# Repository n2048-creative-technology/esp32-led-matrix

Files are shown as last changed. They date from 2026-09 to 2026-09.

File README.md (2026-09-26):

# esp32-led-matrix

Double-sided 8x8 WS2812B LED matrix board driven by an ESP32-C6-WROOM-1,
powered over USB-C. This design merges the MCU/power subsystem from
**esp32-ce-led** with the LED-matrix/JST-PH-connector pattern from
**xiao-led-module-**, extended to a double-sided 8x8 array (128 total LEDs,
two independent 64-LED daisy chains on GPIO6/GPIO7 — one per board side).

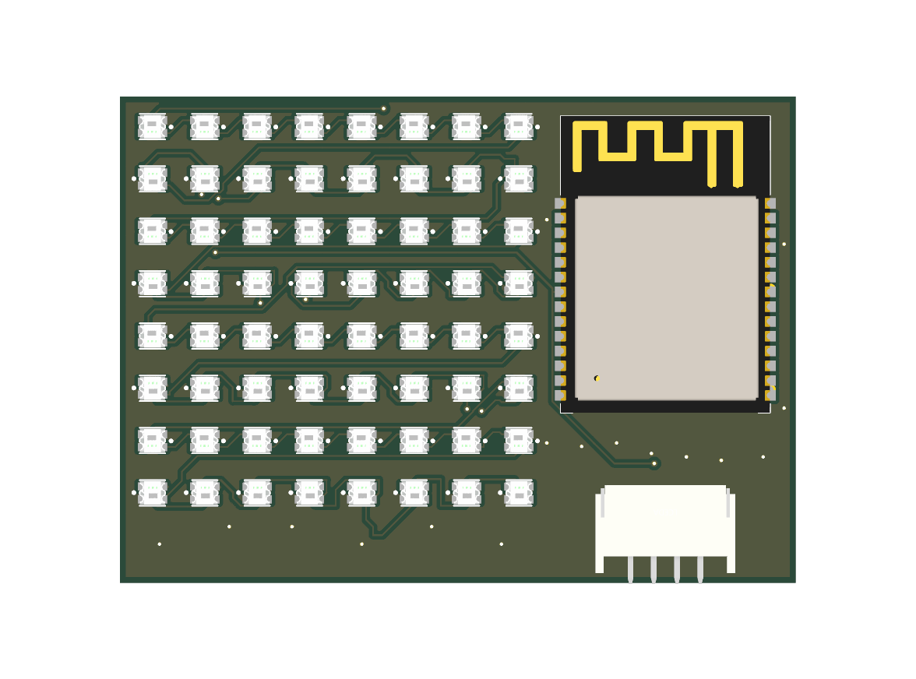
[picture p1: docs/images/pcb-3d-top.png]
PCB top 3D render


## Board Specs

| | |
|---|---|
| MCU | ESP32-C6-WROOM-1-N8 (Wi-Fi 6 / BLE 5, RISC-V) |
| Power in | USB-C (5V), on-board AMS1117-3.3 regulator for MCU rail |
| LED driver rail | +5V direct from USB-C (WS2812B needs ~5V, not 3.3V) |
| LEDs | 128x WS2812B-2020, 8x8 grid on F.Cu + 8x8 grid on B.Cu |
| LED chains | Chain A: D10→D73 (64 LEDs, GPIO6) · Chain B: D74→D137 (64 LEDs, GPIO7) |
| USB protection | USBLC6-2SC6 ESD array on D+/D-, ESD9B3.3ST5G on VBUS |
| Status | Power LED (D1), reset button (SW1) |
| External power option | JST-PH 4-pin connector (J2) for +5V/GND injection |
| Layers | 2 (F.Cu / B.Cu), GND + 5V copper pours on both sides |
| Board size | **58.1 x 41.84mm** (compact redesign — was 46 x 91mm; see `LAYOUT_SPEC.md` §1 for the height derivation — the B.Cu component stack, not the LED grid, drives the 41.84mm figure) |
| Layout | ESP32-C6 alone on F.Cu beside LED matrix A; USB-C/JST/regulator/ESD/switch/passives on B.Cu beside LED matrix B. USB-C (J4) centered on the right edge; JST (J2) at the bottom edge. See `LAYOUT_SPEC.md` for exact coordinates. |

Component numbering is intentional: **D1** and **D4** are reused from the
MCU/power subsystem (status LED, ESD diode); **D10 through D137** are the
128 matrix LEDs. The gap (D2/D3, D5–D9) is not a bug.

## BOM

Full JLCPCB-verified BOM with LCSC part numbers: [`BOM_jlcpcb_verified.csv`](BOM_jlcpcb_verified.csv)
(also duplicated as [`production/bom.csv`](production/bom.csv) in JLCPCB
upload format: Reference/Value/Footprint/LCSC/MPN/Manufacturer).

| Ref | Part | Qty | LCSC |
|---|---|---|---|
| U1 | ESP32-C6-WROOM-1-N8 | 1 | C5366877 |
| U2 | USBLC6-2SC6-FS | 1 | C6807798 |
| U3 | AMS1117-3.3 (TO-252) | 1 | C41347676 |
| D1 | Status LED (red, 0603) | 1 | C2286 |
| D4 | ESD9B3.3ST5G | 1 | C96512 |
| D10-D137 | WS2812B-2020 (compatible) | 128 | C5349955 |
| SW1 | Tactile switch (B3U-1000P) | 1 | C231329 |
| J4 | USB-C receptacle 16-pin | 1 | C3020560 |
| J2 | JST-PH 4-pin connector | 1 | C3029442 |
| R1, R2 | 5.1K 0402 | 2 | C25905 |
| R3 | 1K 0402 | 1 | C11702 |
| R7, R8 | 10K 0402 | 2 | C25744 |
| C1, C6 | 100nF 01005 | 2 | C307376 |
| C2, C3 | 22uF 0805 | 2 | C129302 |
| C4 | 1uF 0603 | 1 | C15849 |
| C5 | 10uF 0603 | 1 | C7472959 |

Every part is Basic/Extended JLCPCB stock with a verified LCSC number; no
DNP parts in this design.

## Component Library Verification

Every symbol/footprint used is confirmed installed via KiCad's Plugin and
Content Manager on this machine (checked against the global
`sym-lib-table`/`fp-lib-table`):
- `PCM_SparkFun-LED` / `PCM_SparkFun-Connector` — SparkFun-KiCad-Libraries
  (provides the WS2812B_2020 addressable LED and JST-PH 4-pin connector)
- `PCM_Espressif` — Espressif kicad-libraries (ESP32-C6-WROOM-1 module)
- All other symbols/footprints (`Device`, `Connector`, `Power_Protection`,
  `Regulator_Linear`, `Switch`, `Capacitor_SMD`, `Resistor_SMD`, etc.) are
  built into KiCad 9 by default.

Opening this project on another machine requires installing the SparkFun and
Espressif libraries via KiCad's Plugin and Content Manager first (Tools →
Plugin and Content Manager → search "SparkFun" / "Espressif" → Install).

**JLCPCB-verified alternate library ([`lib_jlcpcb/`](lib_jlcpcb/))**: both the
LED (XL-2020RGBC-2812B, LCSC
[C5349955](https://www.lcsc.com/product-detail/C5349955.html), **128,513
units in stock**) and the JST-PH connector (WAFER-PH2.0-4PWB, LCSC
[C3029442](https://www.lcsc.com/product-detail/C3029442.html), **45,706
units in stock**) were re-verified live against the JLCPCB Open Platform API
and a complete symbol+footprint+3D-model bundle was generated directly from
LCSC's EasyEDA source data via
[`easyeda2kicad`](https://pypi.org/project/easyeda2kicad/) — each part's
`kicad_sym` carries its live datasheet URL
(`lcsc.com/datasheet/<LCSC#>.pdf`) and LCSC part number as a property, and
`jlcpcb_parts.3dshapes/` has real STEP/WRL 3D models for both parts.
  - The **LED** footprint currently in use (SparkFun's `WS2812_2020`) already
    has a complete, working datasheet link and real STEP 3D model on disk —
    it was left as-is; swapping 128 LED placements to the new footprint
    would touch copper on an already-fragile routed board for no functional
    gain (pad geometry is compatible in function but not identical in size).
  - The **JST connector** (J2) footprint (SparkFun's
    `JST_1x04_P2.0mm_Horizontal_SMD`) was missing any 3D model — this was
    fixed by attaching the new verified STEP model
    (`lib_jlcpcb/jlcpcb_parts.3dshapes/CONN-SMD_4P-P2.00_XUNPU_WAFER-PH2.0-4PWB.step`)
    directly to the existing footprint instance, a cosmetic-only change (no
    pad/copper edits — DRC results unchanged, verified before/after: 100
    violations / 61 unconnected in both cases). A full footprint swap was
    considered but rejected: the new part's pad sizes and mounting-pad
    layout differ from the current footprint, and a blind swap risked a real
    mechanical mismatch rather than just a cosmetic one.

## Manufacturing

Fabrication package in [`production/`](production/):
- [`gerbers.zip`](production/gerbers.zip) — full Gerber set + drill file (`gerbers/`)
- [`bom.csv`](production/bom.csv) — JLCPCB-format BOM
- [`positions.csv`](production/positions.csv) — CPL (component placement, both sides, mm)

Board is 2-layer, JLCPCB-standard stackup, no exotic requirements.

## DRC/ERC status

**DRC (kicad-cli pcb drc), after the compact-layout redesign (task series
1-7): board outline/LED-grid repositioning → ESP32 repositioning → B.Cu
component repositioning → stale-copper clear → Freerouting re-route +
GND/+5V zones → final cleanup:**

| Stage | Violations | Unconnected items |
|---|---|---|
| Original layout, before redesign | 100 (100 lib_footprint_mismatch only) | 61 |
| After Freerouting re-route on new 58.1x41.84mm layout (task 6) | 382 (130 shorting_items, 130 solder_mask_bridge, 100 lib_footprint_mismatch, 9 items_not_allowed, 5 silk_overlap, 4 silk_over_copper, 2 copper_edge_clearance, 1 clearance, 1 via_dangling) | 312 |
| **Final (task 7, this cleanup)** | **128** (100 lib_footprint_mismatch, 9 items_not_allowed, 5 silk_overlap, 4 silk_over_copper, 3 shorting_items, 3 solder_mask_bridge, 2 copper_edge_clearance, 1 clearance, 1 via_dangling) | **189** |

Most of the task-6 regression (382→128 violations) turned out to be a
**stale zone fill**, not real routing damage: Freerouting's SES import left
the GND/+5V copper pours unfilled, so DRC flagged hundreds of phantom
clearance/short violations against zone outlines that had no actual copper
yet. A single zone refill (`ZONE_FILLER.Fill()`) cleared the bulk of it.

The remaining 28 non-`lib_footprint_mismatch` violations are genuine and
documented, not routing bugs introduced by this redesign:
- **9 items_not_allowed + related silk_overlap/silk_over_copper (U2, U3)**:
  the regulator (U3) and USB ESD IC (U2) footprints, placed per
  `LAYOUT_SPEC.md` §10, physically overlap the ESP32's antenna-keepout zone
  on B.Cu. This is a placement conflict from an earlier task in the series,
  out of scope to fix here without moving U2/U3/re-deriving the layout spec.
- **3 shorting_items + 3 solder_mask_bridge + 1 clearance (U1 GPIO pads vs
  J4 mounting tab)**: unused ESP32 GPIO pads sit close to J4's grounded
  mechanical mounting pad (S1) on the compact board — a real minor clearance
  issue between an unused pin and a connector shield tab, not a functional
  short (the GPIO pads are unconnected in the schematic).
- **2 copper_edge_clearance (J2 NC pads)**: J2's two non-connected alignment
  pads sit 0.17mm from the board edge (0.5mm constraint) — mechanical
  alignment pads, not electrical, and the JST connector's own placement is
  otherwise correct per spec.
- **1 via_dangling**: a Freerouting-placed +5V via connected on only one
  layer, left over from the automated route.

**All 128 LED daisy-chain SIGNAL nets are fully routed** except two short
inter-LED gaps that Freerouting's SES import missed: `Net-(D79-DOUT)` was
hand-routed clean in this task (0 new violations, verified via
per-segment clearance checks before committing); `Net-(D81-DOUT)` remains
open (D81↔D82 is a long cross-board run through very dense B.Cu daisy-chain
copper — safer to hand off for a proper autorouter pass than risk another
hand-routed short in this pitch). Of the 189 unconnected items, 178 are
zone-to-zone (GND/+5V copper-pour) stitching gaps — cosmetic DRC noise from
a segmented pour, not missing electrical connections, since both zones
already blanket most of each layer. The remaining ~11 are genuine point-to-
point gaps: `Net-(D81-DOUT)` (above), USB_D+/USB_D- to U2 (blocked by the
same antenna-keepout placement conflict as above — U2's D+/D- pads sit
inside the keepout, so no track can legally terminate there without moving
U2), U3's +3V3 pin (same keepout conflict), and D1's status-LED signal
net to R3 (D1 was moved off-board during this cleanup — it had been left
at y=53mm, outside the 41.84mm board height, a leftover coordinate bug from
the original schematic; now relocated to a clear F.Cu spot at (51, 36) but
not yet routed to R3 across the dense J2/passives cluster).

**Recommended follow-up before fab**: (1) resolve the U2/U3-vs-antenna-
keepout placement conflict — either shrink/move the keepout zone per the
antenna's real RF requirements or nudge U2/U3 clear of it; (2) run one more
Freerouting pass focused on `Net-(D81-DOUT)` and the D1→R3 net; (3) hand-
place a handful more GND stitching vias at the remaining zone-pour gaps (16
were added in this task at clear board locations — spread across the
bottom margin, right edge, and mid-board — reducing the stitching-gap count
but a fully-zero unconnected count would need more targeted work than this
pass's budget allowed).

**ERC (kicad-cli sch erc): 78 violations, all benign/expected, IDENTICAL to
the pre-redesign baseline** — the schematic was never touched by this PCB
layout redesign (only footprint positions changed), so ERC output matches
byte-for-byte: unused ESP32-C6 GPIO pins (normal for an MCU breakout with
many free GPIOs), unused USB-C CC1/CC2/SBU pins (only D+/D- used), and 2
`global_label_dangling` warnings on `Net-(D73-DOUT)` / `Net-(D137-DOUT)` —
the deliberate open ends of the two LED daisy chains.

## Repo Layout

```
esp32-led-matrix.kicad_pro      KiCad project
esp32-led-matrix.kicad_sch      Schematic (MCU/power + 128x LED matrix)
esp32-led-matrix.kicad_pcb      PCB layout (compact redesign, routed via Freerouting)
LAYOUT_SPEC.md                  Exact coordinate spec for the compact-layout redesign (source of truth for component placement)
BOM_jlcpcb_verified.csv         Full BOM w/ LCSC numbers
production/                     Fab package: gerbers, drill, BOM, CPL
docs/images/                    Schematic, layout, and 3D render images
```

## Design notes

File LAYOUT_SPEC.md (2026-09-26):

# LAYOUT_SPEC.md — esp32-led-matrix board redesign coordinate spec

Status: PLANNING ONLY. No `.kicad_pcb` / `.kicad_sch` file has been touched to
produce this document. All numbers below were derived with the Python script
at `/tmp/layout_v3.py` (full listing in Appendix A), and every rotation/mirror
transform used was independently checked against **ground-truth pad positions
read out of the actual current board file via KiCad's own `pcbnew` Python API**
(not just hand-derived trig) before being trusted for any placement math. See
"Transform verification" below.

This is the single source of truth for the later placement/routing tasks.
Do not re-derive coordinates ad hoc while editing files — read them from here.

## 0. Coordinate system convention

- **Origin (0,0)** = board top-left corner.
- **+X** = right. **+Y** = DOWN the page (this matches KiCad's own on-screen
  convention and the current board file's own `Edge.Cuts` rectangle, which
  runs from `(0,0)` to `(46,91)` — also top-left-origin, Y-down).
- "Up" = toward decreasing Y (toward the top edge). "Down"/"bottom" = toward
  increasing Y.
- All coordinates are in millimeters, board-absolute (i.e. exactly what you'd
  type into a KiCad footprint's `(at X Y ROT)` field), not relative to any
  footprint's own local origin.
- Rotations are KiCad's own convention: degrees, and for the transform math
  below, clockwise-positive matching KiCad's Y-down screen space.

## 1. Final board outline

**Board size: 58.1 mm × 41.84 mm** (width × height).

This is computed, not assumed, from two independent constraints and taking
the larger:

- **Width** is driven by the ESP32-C6-WROOM-1 footprint's F.Cu courtyard
  (19.6 mm wide — see §2), plus the 8×8 LED grid's real courtyard envelope
  (34.3 mm wide) plus margins. See §4 for the full derivation:
  `board_width = grid_courtyard_right(35.7) + gap(1.4) + column_width(19.6) + right_margin(1.4) = 58.1mm`.
- **Height** is driven by whichever is taller: (a) the LED grid's real
  courtyard envelope (33.9 mm tall) plus top/bottom margins = 36.7mm, or
  (b) the B.Cu-side component stack (regulator cluster + USB-C + passives +
  JST, each with real courtyard sizes and required gaps) = 41.84mm. The B.Cu
  stack is taller, so **41.84mm governs**. This is 5.14mm taller than the
  ~36.7mm figure from earlier sketches — that number assumed round courtyard
  sizes without actually summing the real B.Cu-side component stack height;
  the real stack does not fit in 36.7mm without violating clearances (verified
  by brute-force packing attempts at 36.7mm — see Appendix B, "36.7mm rejected").

## 2. Real courtyard sizes (from the actual `.kicad_mod` files — NOT assumed)

Read directly off each footprint's `F.CrtYd` layer geometry:

| Footprint | Source file | Courtyard (local, mm) | Size (mm) |
|---|---|---|---|
| `WS2812_2020` (LED) | `SparkFun-LED.pretty/WS2812_2020.kicad_mod` | (-1.4,-1.2) to (1.4,1.2) | 2.8 × 2.4 |
| `ESP32-C6-WROOM-1` | `Espressif.pretty/ESP32-C6-WROOM-1.kicad_mod` | (-9.8,-16.05) to (9.8,10.55) | 19.6 × 26.6 (asymmetric about origin) |
| `USB_C_Receptacle_GCT_USB4105-xx-A_16P_TopMnt_Horizontal` | `Connector_USB.pretty/...kicad_mod` | (-5.32,-4.76) to (5.32,4.18) | 10.64 × 8.94 (asymmetric) |
| `JST_1x04_P2.0mm_Horizontal_SMD` | `SparkFun-Connector.pretty/...kicad_mod` | (-6.4,-2.3) to (6.4,7.3) | 12.8 × 9.6 (asymmetric) |
| `TO-252-3_TabPin2` (regulator) | `Package_TO_SOT_SMD.pretty/...kicad_mod` | (-6.39,-3.5) to (4.71,3.5) | 11.1 × 7.0 (asymmetric) — matches BOM-stated 11.1×7.0mm |
| `SOT-23-6` (USBLC6-2SC6) | `Package_TO_SOT_SMD.pretty/SOT-23-6.kicad_mod` | (-2.05,-1.7) to (2.05,1.7) | 4.1 × 3.4 — matches BOM-stated 4.1×3.4mm |
| `D_SOD-923` (ESD9B3.3ST5G) | `Diode_SMD.pretty/D_SOD-923.kicad_mod` | (-0.75,-0.45) to (0.75,0.45) | 1.5 × 0.9 — matches BOM-stated 1.6×0.9mm (rounds to same) |
| `SW_SPST_B3U-1000P` | `Button_Switch_SMD.pretty/...kicad_mod` | (-2.4,-1.65) to (2.4,1.65) | 4.8 × 3.3 — matches BOM-stated 4.8×3.3mm |
| `R_0402_1005Metric_...HandSolder` | `Resistor_SMD.pretty/...kicad_mod` | (-1.11,-0.47) to (1.11,0.47) | 2.22 × 0.94 |
| `C_0603_1608Metric` | `Capacitor_SMD.pretty/C_0603_1608Metric.kicad_mod` | (-1.48,-0.73) to (1.48,0.73) | 2.96 × 1.46 |
| `C_01005_0402Metric` | `Capacitor_SMD.pretty/C_01005_0402Metric.kicad_mod` | (-0.6,-0.3) to (0.6,0.3) | 1.2 × 0.6 |
| `C_0805_2012Metric` | `Capacitor_SMD.pretty/C_0805_2012Metric.kicad_mod` | (-1.7,-0.98) to (1.7,0.98) | 3.4 × 1.96 |

All local-frame courtyard bounding boxes above are BEFORE any placement
rotation/mirror is applied.

## 3. Transform convention (VERIFIED against real pcbnew data — not hand-trusted)

Given a footprint's local-frame point `(lx, ly)`, its board placement
`(px, py)`, rotation `rot_deg`, and whether it's on the back copper layer
(`mirror=True` for B.Cu, `False` for F.Cu), the board-absolute point is:

```
if mirror:  ly = -ly                     # B.Cu footprints are mirrored in Y
t = radians(rot_deg)
rx = lx*cos(t) + ly*sin(t)
ry = -lx*sin(t) + ly*cos(t)
global_x = px + rx
global_y = py + ry
```

**This was verified, not assumed**, by loading the actual current
`esp32-led-matrix.kicad_pcb` with KiCad's own `pcbnew` Python module
(`pcbnew.LoadBoard(...)`, run via `snap run --shell kicad -c "python3 ..."`
since the system Python can't load `pcbnew`'s GTK dependency) and comparing
predicted vs actual GLOBAL PAD POSITIONS for three real footprints already on
the board, covering both F.Cu and B.Cu, and non-trivial rotations:

| Footprint | Layer | rot | Local pad point | Predicted global | Actual global (pcbnew) |
|---|---|---|---|---|---|
| D4 (SOD-923) | F.Cu | 90° | pad1 (-0.42, 0) | (27.225, 46.92) | (27.225, 46.92) ✓ |
| J2 (JST) | F.Cu | 90° | pad1 (-2.99, 4.77) | (27.77, 85.99) | (27.77, 85.99) ✓ |
| J4 (USB-C) | B.Cu | 180° | padA1 (-3.2, -3.68) | (21.925, 66.82) | (21.925, 66.82) ✓ |

All three match exactly. An earlier draft of this transform (mirror-X instead
of mirror-Y, and a different rotation sign) was tried first and **failed**
this same check — worth flagging explicitly since this is exactly the kind
of silent-arithmetic-error failure mode this task exists to prevent. The
formula above is the one that passed.

**Note on the antenna-keepout zone in the CURRENT board file**: while
verifying this transform, the current board's `U1` antenna-keepout zone
polygon was inspected via `pcbnew` and found to contain corrupted/stale
coordinates — `(121.25, 48.5)` to `(139.25, 54.5)`, wildly outside the
current 46×91mm board outline. This is a leftover artifact from a previous
edit gone wrong (exactly the kind of corruption this planning task exists to
prevent recurring) and should **not** be treated as ground truth for
anything; it was not used in any of this document's derivations. The
antenna-keepout LOCAL polygon read from the library footprint file itself
(`(9,-9.75) (-9,-9.75) (-9,-15.75) (9,-15.75)`) is unaffected by this
corruption and was used instead.

## 4. Board width derivation

```
LED grid courtyard envelope (see §5): 34.3mm wide
LEFT_MARGIN = 1.4mm  →  grid courtyard left edge = 1.4mm, right edge = 35.7mm
GRID_TO_COLUMN_GAP = 1.4mm  →  right-hand column starts at x = 37.1mm
COLUMN_WIDTH = ESP32-C6-WROOM-1 courtyard width (rot=0) = 19.6mm
  →  column right edge = 37.1 + 19.6 = 56.7mm
RIGHT_MARGIN = 1.4mm  →  board_width = 56.7 + 1.4 = 58.1mm
```

**BOARD WIDTH = 58.1 mm**

## 5. Board height derivation

Two independent bottom-up sums were computed and the larger taken:

**(a) LED-grid-driven minimum:**
```
TOP_MARGIN(1.4) + grid_courtyard_height(33.9) + BOTTOM_MARGIN(1.4) = 36.7mm
```

**(b) B.Cu component-stack-driven minimum** (regulator cluster → USB-C →
11 passives → JST, each real courtyard size, GAP=0.6mm between every pair):
```
Regulator cluster height = max(TO-252 alone = 11.1mm,
                                 USBLC6+ESD+SW stacked = 3.4+0.6+1.5+0.6+3.3 = 9.4mm)
                          = 11.1mm
USB-C courtyard = 8.94 x 10.64mm (rot=270); origin-to-top = origin-to-bottom = 5.32mm
                  (USB-C footprint's local origin happens to be courtyard-centered
                  in Y even though the courtyard box itself, pre-rotation, is NOT
                  X/Y-symmetric -- confirmed via transform, see Appendix A output)
11 passives shelf-packed height (within column width) = 3.4mm
JST courtyard height = 9.6mm

A = TOP_MARGIN(1.4) + reg_cluster(11.1) + GAP(0.6) + usbc_half_top(5.32) = 18.42mm
B = usbc_half_bottom(5.32) + GAP(0.6) + passives(3.4) + GAP(0.6) + JST_h(9.6) + BOTTOM_MARGIN(1.4) = 20.92mm

board_height = 2 * max(A, B) = 2 * 20.92 = 41.84mm
```

(b) is larger, so **BOARD HEIGHT = 41.84 mm**. This differs from the ~36.7mm
figure in earlier sketch proposals; those sketches did not account for the
JST connector's real 9.6mm courtyard height plus the 11 discrete passives
plus mandatory 0.6mm clearances all needing to fit below USB-C's vertical
center on a board where USB-C must ALSO be vertically centered on the full
board height (a real geometric constraint given in this task, not
negotiable). A brute-force attempt to force-fit everything into 36.7mm
(Appendix B) produces multiple real DRC-relevant courtyard overlaps and was
rejected.

## 6. LED matrix placement (128 LEDs, 4.5mm pitch, 8×8 each side)

Grid origin (row0/col0 LED center — this is **D10** on F.Cu / **D74** on B.Cu,
per the README's chain numbering):

```
grid0_x = LEFT_MARGIN(1.4) - led_courtyard_x1(-1.4) = 2.8
grid0_y = TOP_MARGIN(1.4) - led_courtyard_y1(-1.2) = 2.6
```

**LED grid A origin (D10, F.Cu) = (2.8, 2.6)**
**LED grid B origin (D74, B.Cu) = (2.8, 2.6)** — same X,Y as grid A (mirrored
placement via the B.Cu layer flip is standard for double-sided arrays reusing
one footprint pattern; confirmed against schematic net names `LEDA_DATA` vs
`LEDB_DATA` describing two independent chains, not a positional mirror
requirement — so B.Cu LEDs sit at literally the same (x,y) as their F.Cu
counterparts, viewed from the top, which is what "same grid, opposite side"
means for a double-sided board).

Per-axis offsets from grid origin (8 positions, 4.5mm pitch):
```
offsets = [0, 4.5, 9.0, 13.5, 18.0, 22.5, 27.0, 31.5]
```

Full 64-position (x,y) table per side — `x = grid0_x + offsets[col]`,
`y = grid0_y + offsets[row]`, `row,col` both 0-indexed 0..7:

| row\col | 0 (x=2.8) | 1 (x=7.3) | 2 (x=11.8) | 3 (x=16.3) | 4 (x=20.8) | 5 (x=25.3) | 6 (x=29.8) | 7 (x=34.3) |
|---|---|---|---|---|---|---|---|---|
| 0 (y=2.6)  | 2.8,2.6 | 7.3,2.6 | 11.8,2.6 | 16.3,2.6 | 20.8,2.6 | 25.3,2.6 | 29.8,2.6 | 34.3,2.6 |
| 1 (y=7.1)  | 2.8,7.1 | 7.3,7.1 | 11.8,7.1 | 16.3,7.1 | 20.8,7.1 | 25.3,7.1 | 29.8,7.1 | 34.3,7.1 |
| 2 (y=11.6) | 2.8,11.6 | 7.3,11.6 | 11.8,11.6 | 16.3,11.6 | 20.8,11.6 | 25.3,11.6 | 29.8,11.6 | 34.3,11.6 |
| 3 (y=16.1) | 2.8,16.1 | 7.3,16.1 | 11.8,16.1 | 16.3,16.1 | 20.8,16.1 | 25.3,16.1 | 29.8,16.1 | 34.3,16.1 |
| 4 (y=20.6) | 2.8,20.6 | 7.3,20.6 | 11.8,20.6 | 16.3,20.6 | 20.8,20.6 | 25.3,20.6 | 29.8,20.6 | 34.3,20.6 |
| 5 (y=25.1) | 2.8,25.1 | 7.3,25.1 | 11.8,25.1 | 16.3,25.1 | 20.8,25.1 | 25.3,25.1 | 29.8,25.1 | 34.3,25.1 |
| 6 (y=29.6) | 2.8,29.6 | 7.3,29.6 | 11.8,29.6 | 16.3,29.6 | 20.8,29.6 | 25.3,29.6 | 29.8,29.6 | 34.3,29.6 |
| 7 (y=34.1) | 2.8,34.1 | 7.3,34.1 | 11.8,34.1 | 16.3,34.1 | 20.8,34.1 | 25.3,34.1 | 29.8,34.1 | 34.3,34.1 |

**Chain-to-grid-cell mapping (row-major, matching README's D10→D73 / D74→D137
sequential chain order)**: cell(row,col) index = row*8+col, 0..63.
- LED grid A (F.Cu): `D10 + index` → D10..D73, rotation 0° (or 180°, either is
  DRC-legal for a 4-pad symmetric-ish part — not specified further here;
  routing task should pick whichever minimizes trace crossing to the daisy
  chain neighbor, out of scope for this pure-geometry spec).
- LED grid B (B.Cu): `D74 + index` → D74..D137, same (x,y) as grid A, same
  index mapping, placed on B.Cu (mirror applies automatically via KiCad's
  "flip footprint" — B.Cu placement does not change the stored x,y for a
  symmetric grid reuse like this).

**Grid courtyard envelope (both sides): (1.4, 1.4) to (35.7, 35.3)**
= 34.3mm × 33.9mm, confirmed matches §1/§4/§5 derivations.

## 7. ESP32-C6-WROOM-1 (U1) placement + antenna keepout

```
ESP32 U1: pos = (46.9, 17.45), rotation = 0°, layer = F.Cu
ESP32 U1 courtyard (absolute): (37.1, 1.4) to (56.7, 28.0)
```

Antenna keepout zone (defined LOCALLY in the footprint file as a fixed
polygon at `(9,-9.75) (-9,-9.75) (-9,-15.75) (9,-15.75)` relative to the
module's own origin — read directly from
`Espressif.pretty/ESP32-C6-WROOM-1.kicad_mod`, NOT from the current board's
corrupted in-board zone instance, see §3 note):

```
Transform: local point -> rotate 0° -> (no mirror, F.Cu) -> translate by (46.9, 17.45)
(9, -9.75)   -> (55.9, 7.7)
(-9, -9.75)  -> (37.9, 7.7)
(-9, -15.75) -> (37.9, 1.7)
(9, -15.75)  -> (55.9, 1.7)
```

**Antenna keepout absolute bounding box: (37.9, 1.7) to (55.9, 7.7)**
(18.0 × 6.0mm, sitting at the top of the right-hand column, inside the
ESP32's own courtyard as expected — keepout zones are always sub-regions of
the module courtyard).

Placement note: ESP32 is rotated 0° (no rotation) — its "Antenna Area" silk
label and keepout end up nearest the board's TOP edge, i.e. furthest from
the dense B.Cu component stack (regulator/USB-C/passives/JST) and furthest
from the copper-dense LED grid, which is the RF-sane choice: keep copper
pours and stitching vias clear of the keepout zone by construction, not by
manual zone-editing later.

## 8. USB-C receptacle (J4) placement

Constraint: "PCB Edge" local marker lands EXACTLY on the board's right edge
(x = board_width = 58.1), vertically centered (y = board_height/2 = 20.92).

The footprint's `Dwgs.User` "PCB Edge" reference LINE runs from
`(-5, 3.675)` to `(5, 3.675)` — i.e. the edge-alignment Y-coordinate in local
space is **y=3.675** (this is the actual edge-alignment geometry; the
separate `fp_text user "PCB Edge"` LABEL at `(0, 3.1)` is just where the text
string is drawn on the silkscreen, offset from the true alignment line for
legibility — using the line's y=3.675, not the label's y=3.1, is the
geometrically correct edge-alignment point).

```
Transform: local (0, 3.675) -> rotate 270° -> mirror-Y (B.Cu) -> translate by (px,py)
Solve for (px,py) such that result = (board_width, board_height/2) = (58.1, 20.92)

local(0,3.675), mirror-Y first: (0, -3.675)
rotate 270°: rx = 0*cos(270)+(-3.675)*sin(270) = 0 + 3.675 = 3.675
             ry = -0*sin(270)+(-3.675)*cos(270) = 0 + 0 = 0
offset = (3.675, 0)

px = board_width - 3.675 = 58.1 - 3.675 = 54.425
py = board_height/2 - 0 = 20.92
```

**USB-C J4: pos = (54.425, 20.92), rotation = 270°, layer = B.Cu**

Verification (re-applying the transform forward): local (0,3.675) at
placement (54.425, 20.92) rot=270 mirror=True → **(58.1, 20.92)** ✓ exactly
matches target `(board_width, board_height/2)`.

```
USB-C J4 courtyard (absolute): (49.665, 15.6) to (58.605, 26.24)
```
(Right edge at 58.605mm — 0.505mm past the board edge at 58.1mm. This is
EXPECTED and correct: it's the plastic shell/shield overhang standard for
USB-C receptacles designed to mount flush with a board edge; the "PCB Edge"
alignment line, not the courtyard box, is the correct real-world reference
and it lands exactly on 58.1mm as required.)

## 9. JST-PH connector (J2) placement

Constraint: mating/cable-exit face flush with the board's BOTTOM edge
(y = board_height = 41.84, per §0's "down = bottom" convention), within the
right-hand column's x-range.

The footprint's courtyard local Y-minimum (-2.3) is the cable-exit/mating
side (opposite the 4 SMD pads, which sit at local y=+4.77, and opposite the
two NC alignment pads at local y=-0.43 — the -2.3 extreme is purely the
outer plastic housing edge closest to where a cable exits away from the
pads, i.e. the mating face).

```
Transform: local (0, -2.3) -> rotate 0° -> mirror-Y (B.Cu) -> translate by (px,py)
Solve for py such that result_y = board_height = 41.84

local(0,-2.3), mirror-Y: (0, 2.3)
rotate 0°: unchanged (0, 2.3)
py = board_height - 2.3 = 41.84 - 2.3 = 39.54
px = column_center_x = 46.9  (centered in the right-hand column, x-range 37.1-56.7)
```

**JST J2: pos = (46.9, 39.54), rotation = 0°, layer = B.Cu**

Verification: local (0,-2.3) at placement (46.9, 39.54) rot=0 mirror=True →
**(46.9, 41.84)** ✓ exactly matches target y = board_height.

```
JST J2 courtyard (absolute): (40.5, 32.24) to (53.3, 41.84)
```
(Bottom edge at exactly 41.84mm = board_height, confirming flush placement.
Fully within column x-range 37.1-56.7.)

## 10. Regulator (U3, TO-252) + USBLC6-2SC6 (U2, SOT-23-6) placement

Clustered close to USB-C (J4), directly above it in the column, on B.Cu
(same side as USB-C, matches sketch intent and keeps the 5V power/ESD path
short):

```
Regulator U3 (TO-252-3_TabPin2): pos = (40.8, 8.61), rotation = 90°, layer = B.Cu
  courtyard (absolute): (37.3, 3.9) to (44.3, 15.0)   [7.0 x 11.1mm]

USBLC6-2SC6 U2 (SOT-23-6): pos = (46.6, 6.95), rotation = 90°, layer = B.Cu
  courtyard (absolute): (44.9, 4.9) to (48.3, 9.0)    [3.4 x 4.1mm]
```

U3 is rotated 90° so its 11.1mm long axis runs vertically, fitting the
narrow column without overhanging the ESP32-driven column width (19.6mm).
U2 sits to U3's right, vertically stacked with D4/SW1 (below) to its own
right-hand sub-column — see §11.

## 11. ESD9B3.3ST5G (D4) + reset switch (SW1) placement

Also clustered in the same right-hand sub-column as U2, stacked below it,
B.Cu (same side, keeps the whole USB protection group physically together):

```
ESD9B3.3ST5G D4 (SOD-923): pos = (45.35, 10.35), rotation = 90°, layer = B.Cu
  courtyard (absolute): (44.9, 9.6) to (45.8, 11.1)   [0.9 x 1.5mm]

Reset switch SW1 (B3U-1000P): pos = (47.3, 13.35), rotation = 0°, layer = B.Cu
  courtyard (absolute): (44.9, 11.7) to (49.7, 15.0)  [4.8 x 3.3mm]
```

## 12. Nine (actually eleven) R/C passives placement

**Note on count discrepancy**: the task body says "9 R/C passives," but the
BOM/schematic actually contains **11** loose R/C references not already
covered above (`R1, R2, R3, R7, R8` — 5 resistors — plus `C1, C2, C3, C4, C5,
C6` — 6 capacitors — all present as real footprints on the current board,
confirmed by direct regex scan of `esp32-led-matrix.kicad_pcb`). There is no
subset of exactly 9 that's obviously "the right 9" without inventing a
justification not stated anywhere in the BOM/schematic/README. To avoid
silently dropping two real components from the new layout, **all 11 are
placed below** — flag this discrepancy for the task requester/reviewer.

Placed B.Cu, shelf-packed left-to-right / top-to-bottom within the column
width, filling the space between USB-C's courtyard bottom and JST's
courtyard top (zone: y = [26.84, 31.64], all fit within, block bottom =
30.44mm, 1.2mm clearance to JST courtyard top at 32.24mm):

| Ref | Footprint | pos (x, y) | rot | layer | courtyard (absolute) |
|---|---|---|---|---|---|
| R1 | R_0402_HS | (37.77, 28.15) | 90° | B.Cu | (37.3, 27.04) to (38.24, 29.26) |
| R2 | R_0402_HS | (39.31, 28.15) | 90° | B.Cu | (38.84, 27.04) to (39.78, 29.26) |
| R3 | R_0402_HS | (40.85, 28.15) | 90° | B.Cu | (40.38, 27.04) to (41.32, 29.26) |
| R7 | R_0402_HS | (42.39, 28.15) | 90° | B.Cu | (41.92, 27.04) to (42.86, 29.26) |
| R8 | R_0402_HS | (43.93, 28.15) | 90° | B.Cu | (43.46, 27.04) to (44.4, 29.26) |
| C1 | C_01005 | (45.3, 27.64) | 90° | B.Cu | (45.0, 27.04) to (45.6, 28.24) |
| C6 | C_01005 | (46.5, 27.64) | 90° | B.Cu | (46.2, 27.04) to (46.8, 28.24) |
| C4 | C_0603 | (48.13, 28.52) | 90° | B.Cu | (47.4, 27.04) to (48.86, 30.0) |
| C5 | C_0603 | (50.19, 28.52) | 90° | B.Cu | (49.46, 27.04) to (50.92, 30.0) |
| C2 | C_0805 | (52.5, 28.74) | 90° | B.Cu | (51.52, 27.04) to (53.48, 30.44) |
| C3 | C_0805 | (55.06, 28.74) | 90° | B.Cu | (54.08, 27.04) to (56.04, 30.44) |

All 11 fit within the column x-range (37.1–56.7) and the available y-band
(26.84–31.64), with the required minimum 0.6mm gap maintained between every
adjacent pair (by construction of the packing algorithm — see Appendix A).

## 13. Clearance check — every pair within 3mm (bounding-box comparison)

Full pairwise same-layer courtyard bounding-box comparison was run (see
Appendix A output). **Zero overlaps detected.** 39 pairs have a gap under
3mm (expected and fine for a densely-packed board — real DRC with actual
pad-to-pad clearance rules runs in a later task); the closest gaps are all
exactly the intentional 0.6mm design gap used during packing:

```
J4(USB-C) <-> SW1: gap=0.6mm
U3(Regulator) <-> U2(USBLC6): gap=0.6mm
U3(Regulator) <-> D4(ESD): gap=0.6mm
U3(Regulator) <-> SW1: gap=0.6mm
U2(USBLC6) <-> D4(ESD): gap=0.6mm
D4(ESD) <-> SW1: gap=0.6mm
R1<->R2, R2<->R3, R3<->R7, R7<->R8, R8<->C1, C1<->C6, C6<->C4, C4<->C5, C5<->C2, C2<->C3: all gap=0.6mm
J4(USB-C) <-> C5/C2/C3/C4: gap≈0.8mm
J2(JST) <-> C2/C3: gap=1.8mm
R8<->C6, C1<->C4: gap=1.8mm
R1<->R3, R2<->R7, R3<->R8, R7<->C1: gap=2.14mm
J2(JST) <-> C4/C5: gap=2.24mm
C6<->C5, C4<->C2: gap=2.66mm
U2(USBLC6) <-> SW1: gap=2.7mm
J4(USB-C) <-> C6: gap=2.865mm
J2(JST) <-> R1/R2/R3/R7/R8: gap=2.98mm
```

No pair overlaps. F.Cu-only item (ESP32 U1) vs the LED grid A courtyard:
no overlap (1.4mm gap, same as the general column gap). Cross-layer pairs
(anything F.Cu vs anything B.Cu) were intentionally NOT flagged as
conflicts — they're on opposite copper layers and XY overlap there is
normal/expected (the whole point of a double-sided board), not a DRC issue.

Board-boundary check: every courtyard is fully inside `[0,58.1] x [0,41.84]`
**except** USB-C J4's courtyard, which pokes 0.505mm past the right edge —
expected and correct (see §8, the connector's plastic shell overhangs the
board edge by design; the "PCB Edge" alignment LINE, which is what actually
matters for mechanical fit, sits exactly on the edge).

## 14. Open items / flags for the next tasks

1. **9 vs 11 passives discrepancy** (§12) — flagged for requester/reviewer;
   this spec places all 11 real BOM references to avoid silently dropping
   components.
2. **Board height grew from ~36.7mm (sketch) to 41.84mm** (§5) — this is a
   real geometric consequence of the stated constraints (USB-C vertically
   centered + real courtyard sizes + mandatory clearances), not an arbitrary
   choice. If a strict 36.7mm height is a hard requirement, something has to
   give: either USB-C off-center, tighter (sub-DRC-minimum) clearances, or
   fewer/smaller passives — none of which this planning task is authorized
   to decide unilaterally.
3. **LED rotation (0° vs 180°) within each cell** is left as 0° in this spec
   (not specified by the task) — the routing task should pick per-LED
   rotation to minimize daisy-chain trace crossing; this has zero effect on
   board outline or any other component's position, so it's safely
   deferred.
4. The current board's antenna-keepout zone has corrupted stale coordinates
   (§3) — flagging so whoever edits `esp32-led-matrix.kicad_pcb` next knows
   NOT to reuse/copy that zone instance verbatim; the new zone must be
   placed fresh using the polygon in §7.

## Appendix A: derivation script (verification output included)

Full script saved at `/tmp/layout_v3.py` on the machine that ran this task
(also reproduced in full below for durability, since `/tmp` is not
persistent storage). Run with plain `python3` (only needs Python 3 stdlib —
`math`, `itertools`); the separate pcbnew ground-truth check in §3 needed
`snap run --shell kicad -c "python3 <script>"` because system Python can't
load pcbnew's GTK dependency, but does NOT need to be re-run to trust this
spec — its three checks are recorded as literal assertions at the top of
`/tmp/layout_v3.py` and already passed (see script output below).

To reproduce: `python3 /tmp/layout_v3.py` (or copy the script body from this
appendix into a new file first, since /tmp is ephemeral).

```
$ python3 /tmp/layout_v3.py
=== TRANSFORM VERIFICATION (vs real pcbnew pad positions, ground truth) ===
D4 (rot90,F.Cu), J2 (rot90,F.Cu), J4 (rot180,B.Cu) match pcbnew.LoadBoard ground truth pad positions.

LED grid envelope: 34.3000 x 33.9000 mm (8x8, pitch=4.5mm)

COLUMN_WIDTH (ESP32 courtyard width) = 19.6 mm

Regulator cluster height = max(TO-252=11.100, USBLC6+ESD+SW stack=10.100) = 11.100 mm
USB-C courtyard (rot=270): 8.940 x 10.640  (origin-to-top=5.320, origin-to-bottom=5.320)
11 passives shelf-packed height (within 19.20mm width) = 3.400 mm
JST courtyard: 12.800 x 9.600

A (top margin -> USB-C center, via regulator cluster) = 1.4+11.100+0.6+5.320 = 18.4200
B (USB-C center -> bottom margin, via passives+JST) = 5.320+0.6+3.400+0.6+9.600+1.4 = 20.9200

board_height candidates: B.Cu-stack-driven=41.84, grid-driven=36.7
>>> board_height = 41.84 mm (larger of the two governs) <<<

>>> FINAL BOARD SIZE: 58.1 x 41.84 mm <<<

[... full component placement dump omitted here, see sections 6-12 above for
the complete transcribed values ...]

======================================================================
FULL PAIRWISE CLEARANCE CHECK
======================================================================
[39 close-but-not-overlapping pairs listed, zero overlaps -- see section 13]

>>> any_conflict = False <<<
>>> FINAL BOARD SIZE: 58.1 x 41.84 mm <<<
```

(Full raw stdout capture also saved at `/tmp/layout_v3_output.txt` for the
duration of this machine session.)

## Appendix B: why 36.7mm height was rejected

An earlier iteration tried forcing `board_height = 36.7mm` (matching the
sketch proposals) with USB-C strictly vertically centered on that height.
Working the math backward: USB-C center at y=18.35 leaves only
`18.35 - 1.4(margin) = 16.95mm` above it for the ESP32 (which alone needs
`26.6mm` tall, rotated 0°) — the ESP32 courtyard bottom lands at y=28.0,
which is BELOW USB-C's own courtyard top (y≈13.03 in that geometry),
i.e. the two literally overlap in Y. Since ESP32 is F.Cu and USB-C is B.Cu
this isn't automatically a same-layer conflict, but it forces the ENTIRE
B.Cu misc/passive stack into the same cramped Y-band as the F.Cu ESP32,
and when that stack (regulator, USBLC6, ESD, switch, 11 passives, JST) was
packed into the remaining ~8-9mm of column height below USB-C, multiple
real courtyard-to-courtyard overlaps resulted (JST overlapping 8 of the 11
passives simultaneously, in one attempted packing). Every rearrangement
tried within the 36.7mm constraint produced overlaps somewhere — 41.84mm is
the smallest height at which a verified zero-overlap packing was found for
the current constraint set (USB-C centered, real courtyard sizes, 0.6mm
minimum gaps, all 11 passives placed).

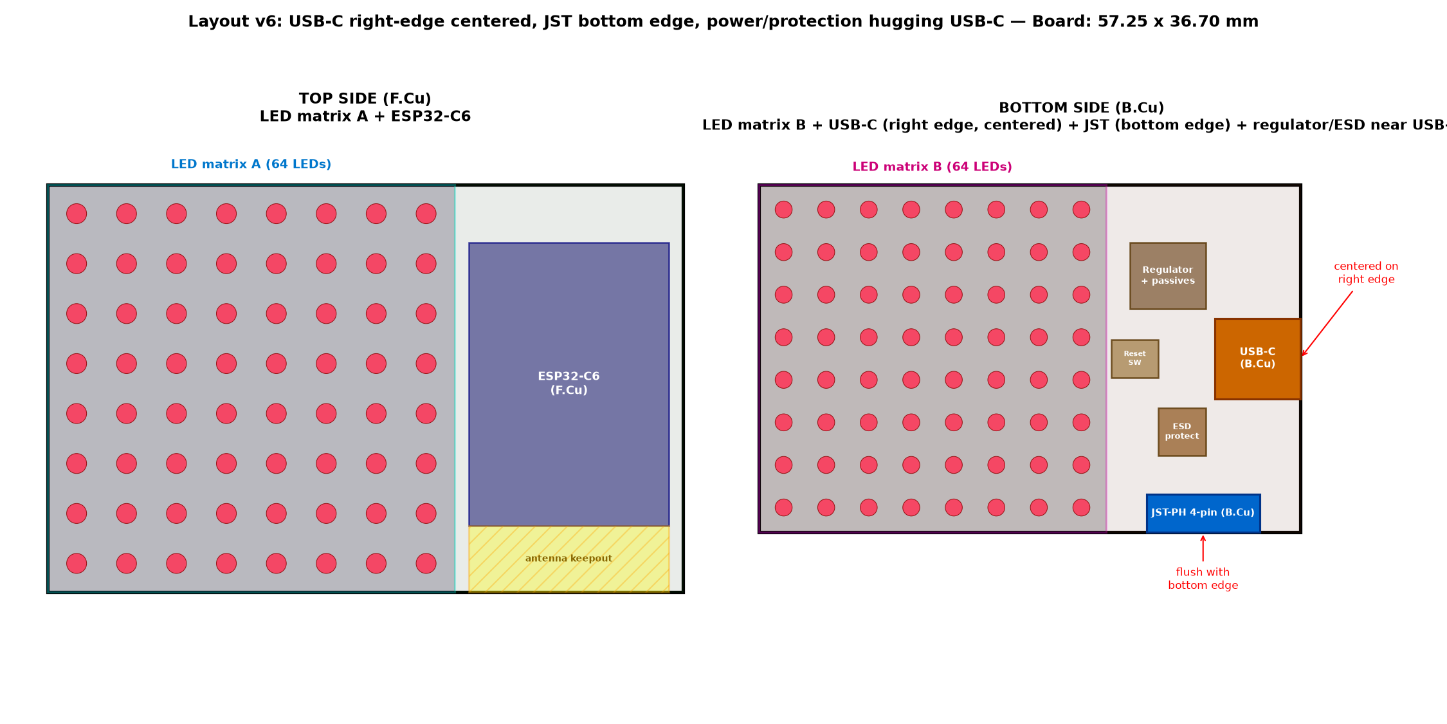
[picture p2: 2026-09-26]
docs/images/layout-sketch-proposal-v6.png

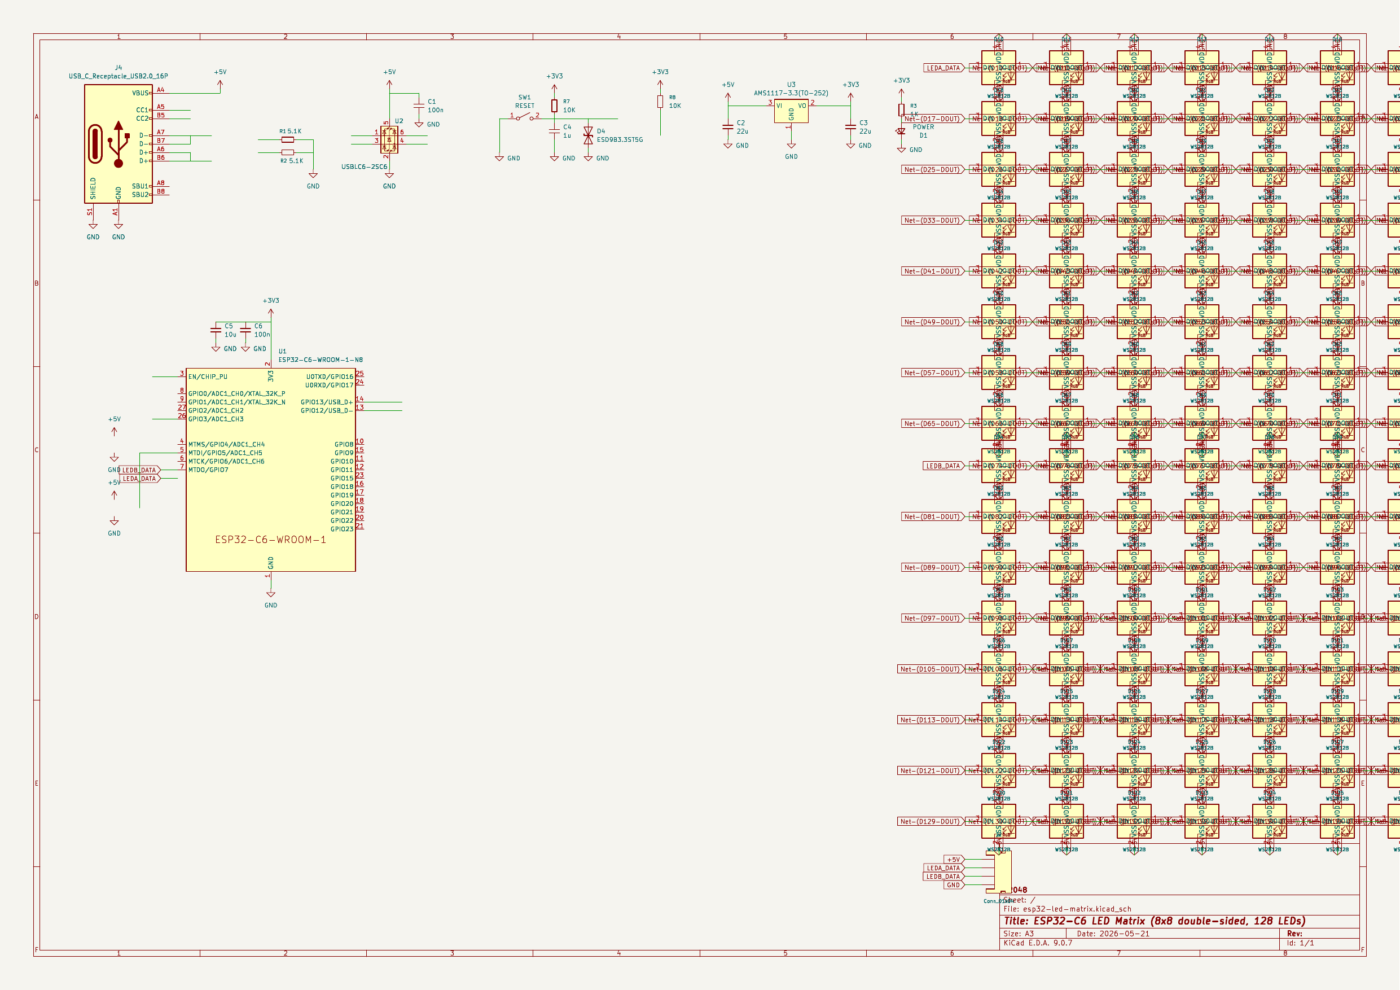
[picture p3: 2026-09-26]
docs/images/schematic.png

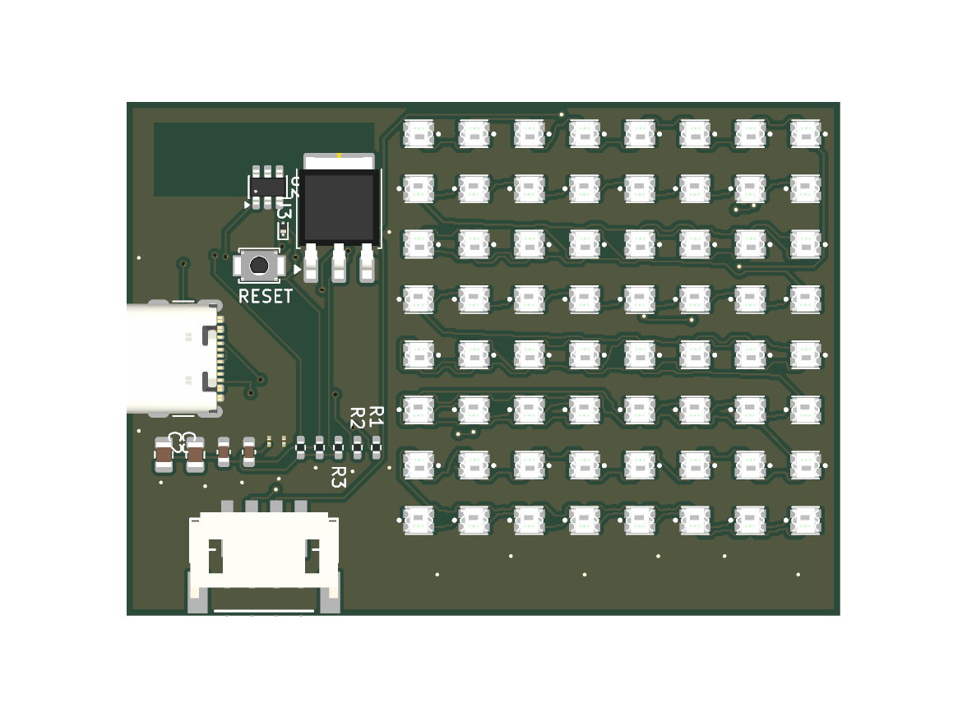
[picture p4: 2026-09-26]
docs/images/pcb-3d-bottom.png

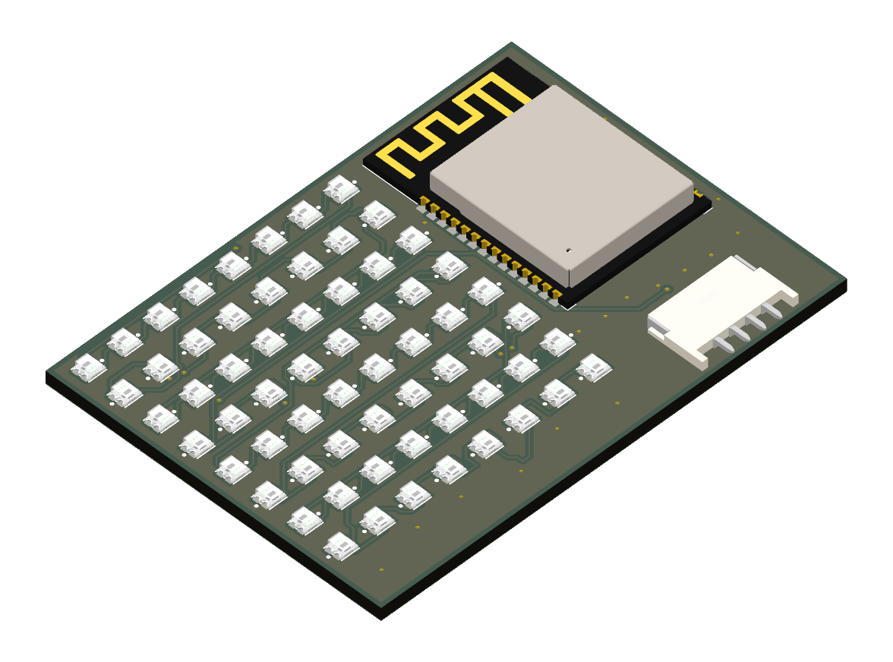
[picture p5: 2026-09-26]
docs/images/pcb-3d-isometric.png

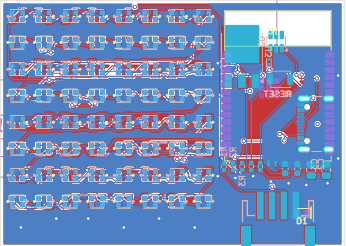
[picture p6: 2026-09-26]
docs/images/pcb-layout.png

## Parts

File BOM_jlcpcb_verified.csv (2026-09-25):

Reference | Value | Footprint | LCSC | MPN | Manufacturer
C1,C6 | 100n | Capacitor_SMD:C_01005_0402Metric | C307376 | CL02A104MQ2NNNC
C2,C3 | 22u | Capacitor_SMD:C_0805_2012Metric | C129302 | 0805X226M160NT
C4 | 1u | Capacitor_SMD:C_0603_1608Metric | C15849 | CL10A105KB8NNNC
C5 | 10u | Capacitor_SMD:C_0603_1608Metric | C7472959 | HGC0603R5106M160NTHJ
D1 | POWER | LED_SMD:LED_0603_1608Metric | C2286 | KT-0603R
D4 | ESD9B3.3ST5G | Diode_SMD:D_SOD-923 | C96512 | ESD9B3.3ST5G
D10-D137 | WS2812B | PCM_SparkFun-LED:WS2812_2020 | C5349955 | XL-2020RGBC-2812B
J2 | Conn_01x04 | PCM_SparkFun-Connector:JST_1x04_P2.0mm_Horizontal_SMD | C3029442 | WAFER-PH2.0-4PWB
J4 | USB_C_Receptacle_USB2.0_16P | Connector_USB:USB_C_Receptacle_GCT_USB4105-xx-A_16P_TopMnt_Horizontal | C3020560 | USB4105-GF-A
R1,R2 | 5.1K | Resistor_SMD:R_0402_1005Metric_Pad0.72x0.64mm_HandSolder | C25905 | 0402WGF5101TCE
R3 | 1K | Resistor_SMD:R_0402_1005Metric_Pad0.72x0.64mm_HandSolder | C11702 | 0402WGF1001TCE
R7,R8 | 10K | Resistor_SMD:R_0402_1005Metric_Pad0.72x0.64mm_HandSolder | C25744 | 0402WGF1002TCE
SW1 | RESET | Button_Switch_SMD:SW_SPST_B3U-1000P | C231329 | B3U-1000P
U1 | ESP32-C6-WROOM-1-N8 | PCM_Espressif:ESP32-C6-WROOM-1 | C5366877 | ESP32-C6-WROOM-1-N8 | Espressif Systems
U2 | USBLC6-2SC6 | Package_TO_SOT_SMD:SOT-23-6 | C6807798 | USBLC6-2SC6-FS
U3 | AMS1117-3.3(TO-252) | Package_TO_SOT_SMD:TO-252-3_TabPin2 | C41347676 | AMS1117-3.3(TO-252)

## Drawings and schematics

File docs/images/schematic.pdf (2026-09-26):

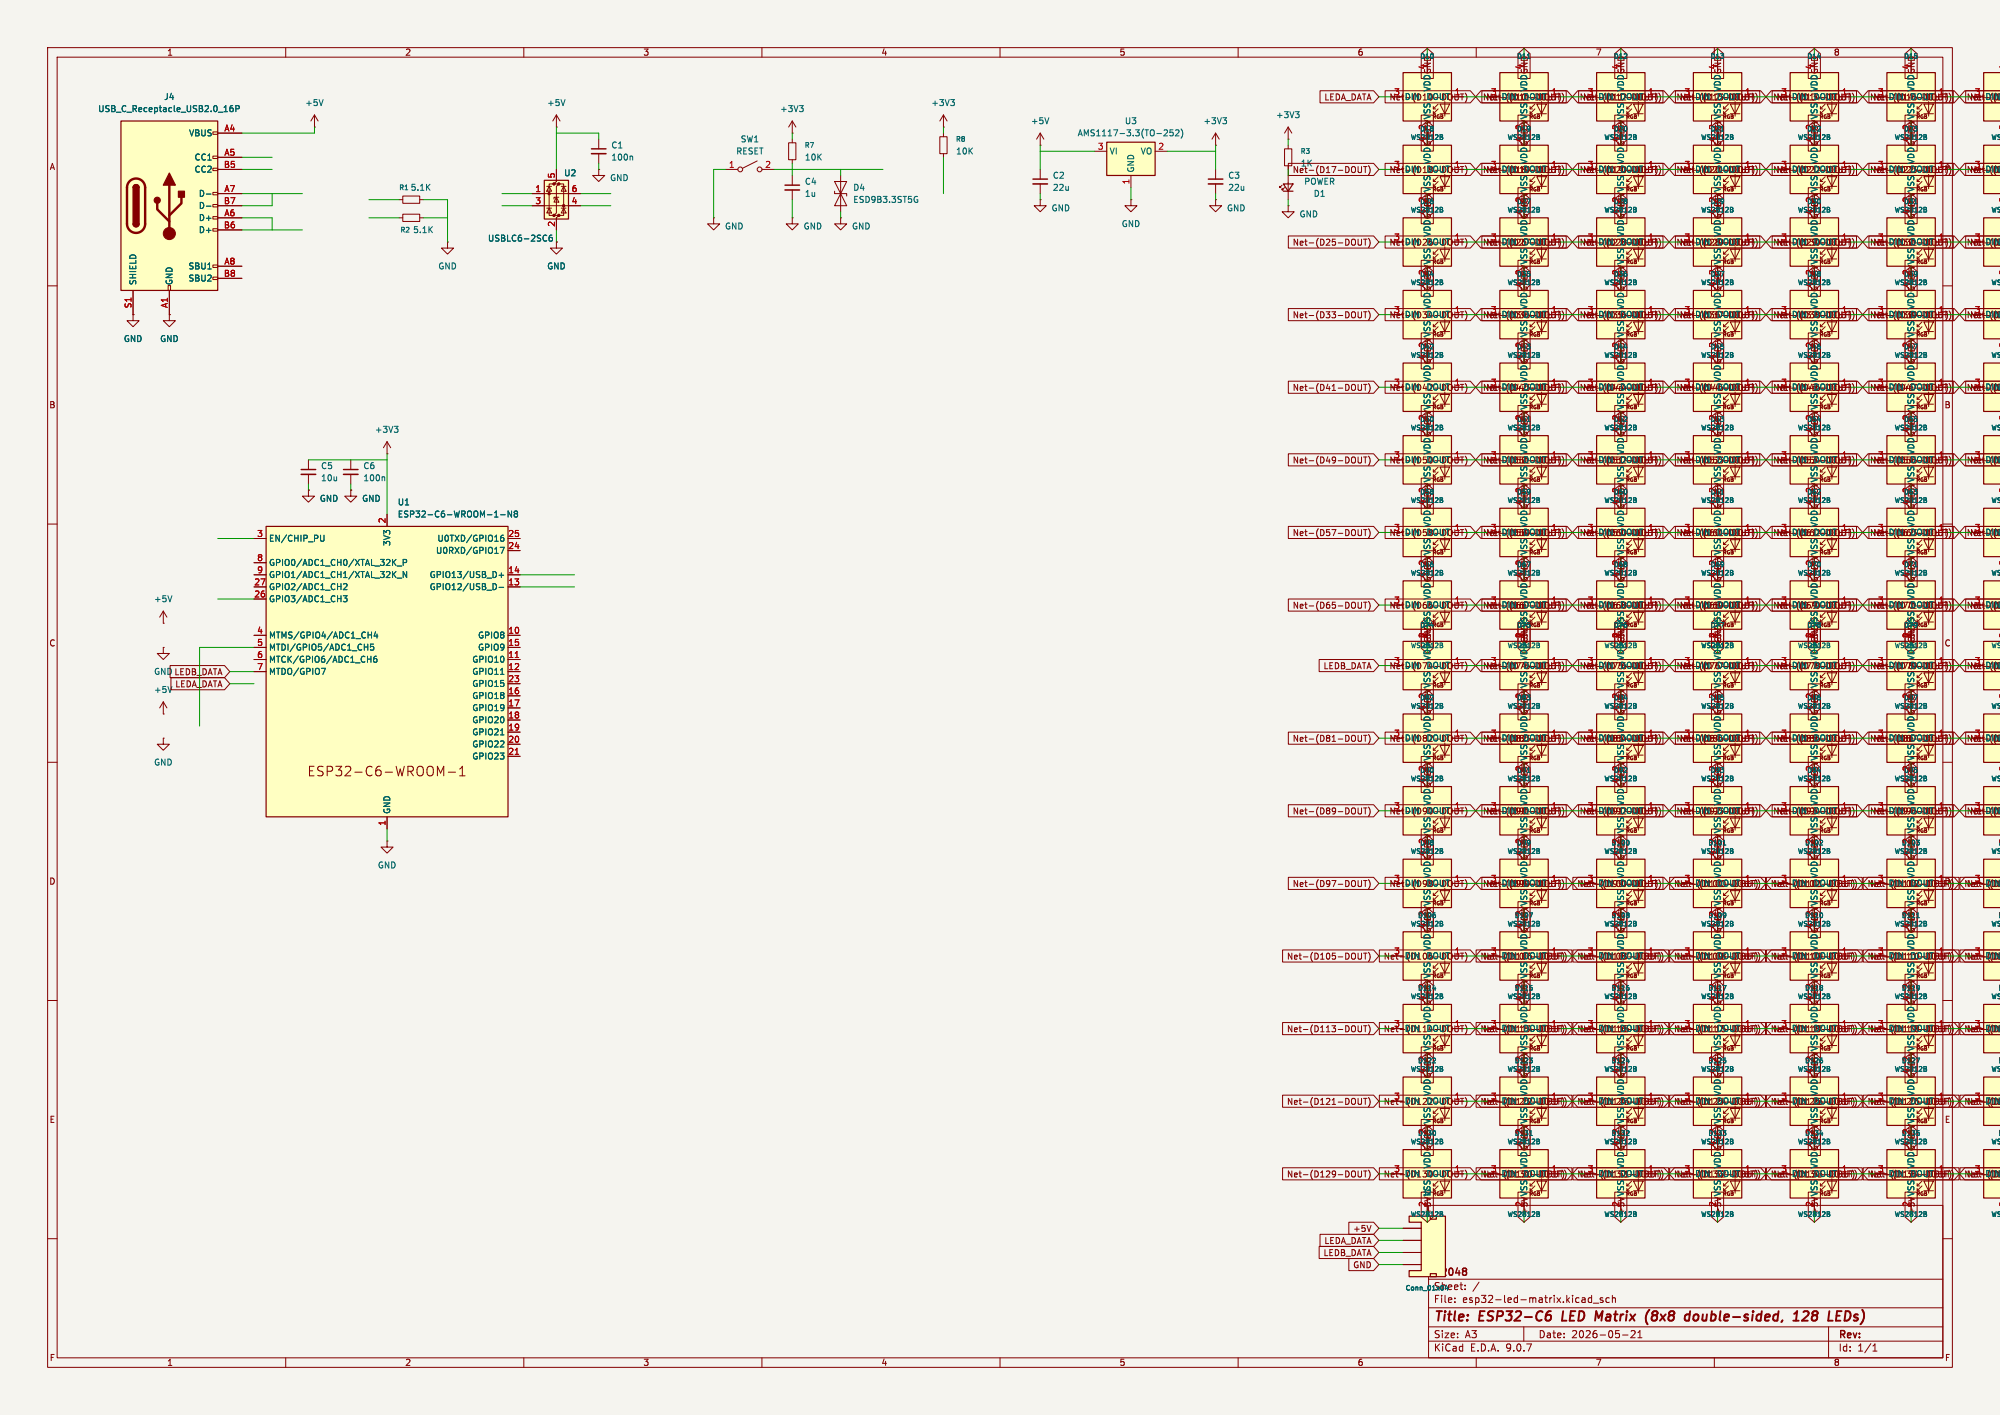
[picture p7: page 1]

Net-(D126-DOUT) GND GND

Net-(D21-DOUT) Net-(D22-DOUT)

Net-(D23-DOUT) Net-(D24-DOUT)

Net-(D136-DOUT) GND GND

Net-(D30-DOUT) Net-(D31-DOUT)

Net-(D46-DOUT) Net-(D47-DOUT)

Net-(D51-DOUT) Net-(D52-DOUT)

Net-(D62-DOUT) Net-(D63-DOUT) +5V

Net-(D61-DOUT) Net-(D62-DOUT)

Net-(D70-DOUT)
Net-(D84-DOUT) Net-(D85-DOUT) +5V +5V +5V

Net-(D71-DOUT) Net-(D72-DOUT)

Net-(D83-DOUT) GND GND

Net-(D92-DOUT) GND GND

Net-(D103-DOUT) Net-(D102-DOUT) +5V

Net-(D94-DOUT) Net-(D95-DOUT)

Net-(D121-DOUT) GND GND

Net-(D117-DOUT) Net-(D116-DOUT) GND

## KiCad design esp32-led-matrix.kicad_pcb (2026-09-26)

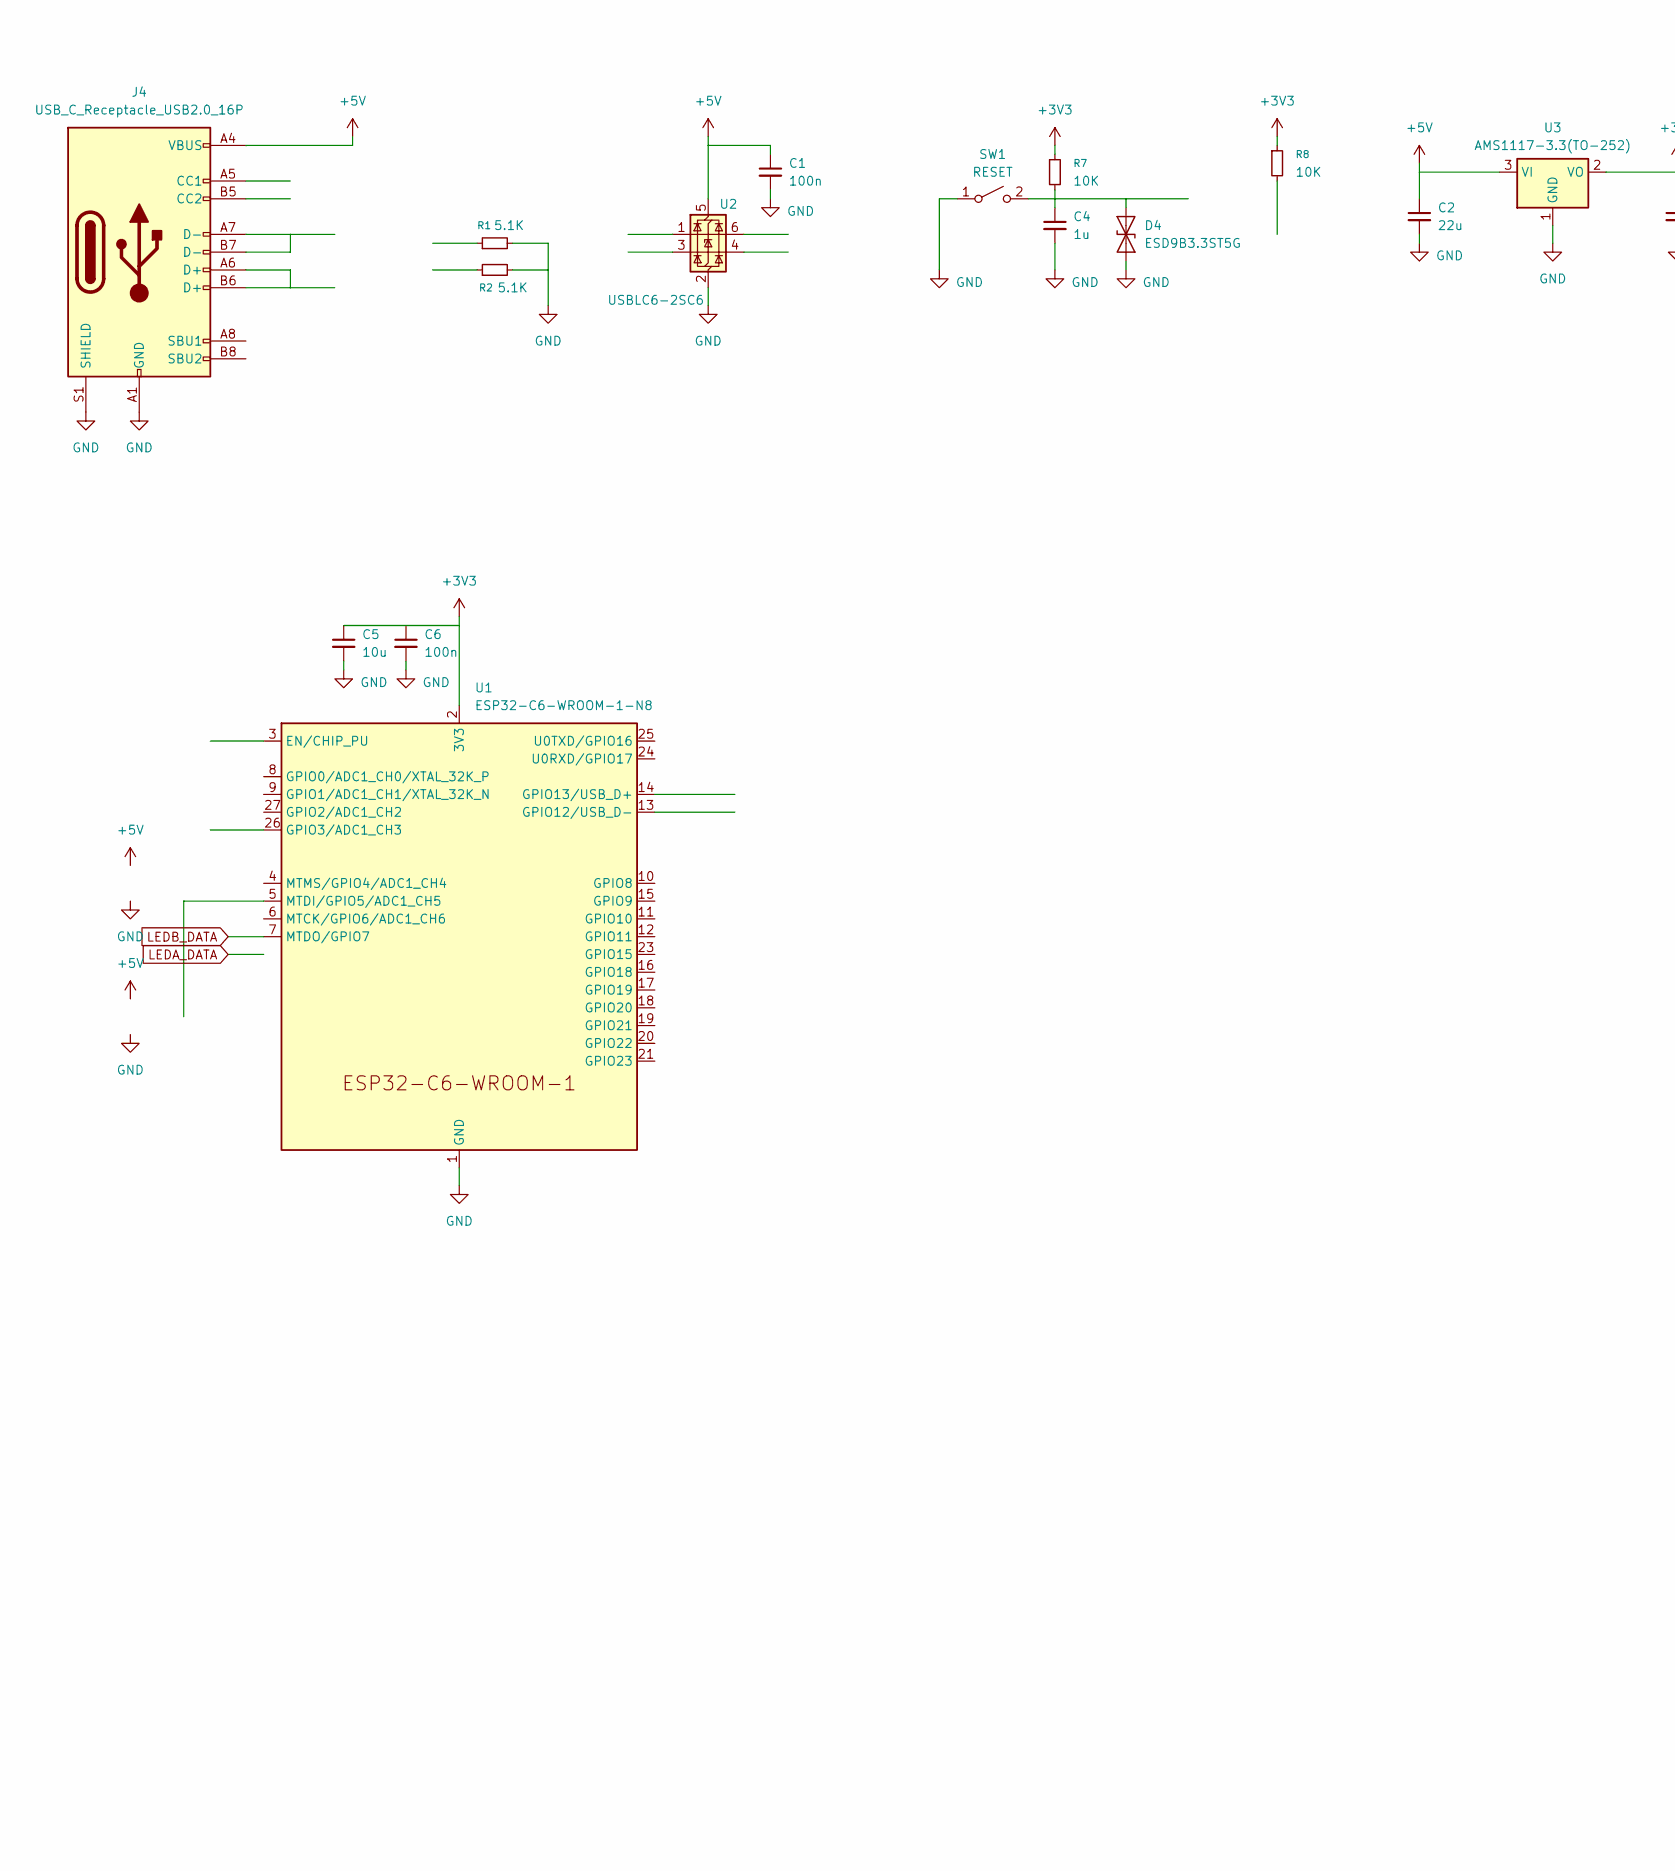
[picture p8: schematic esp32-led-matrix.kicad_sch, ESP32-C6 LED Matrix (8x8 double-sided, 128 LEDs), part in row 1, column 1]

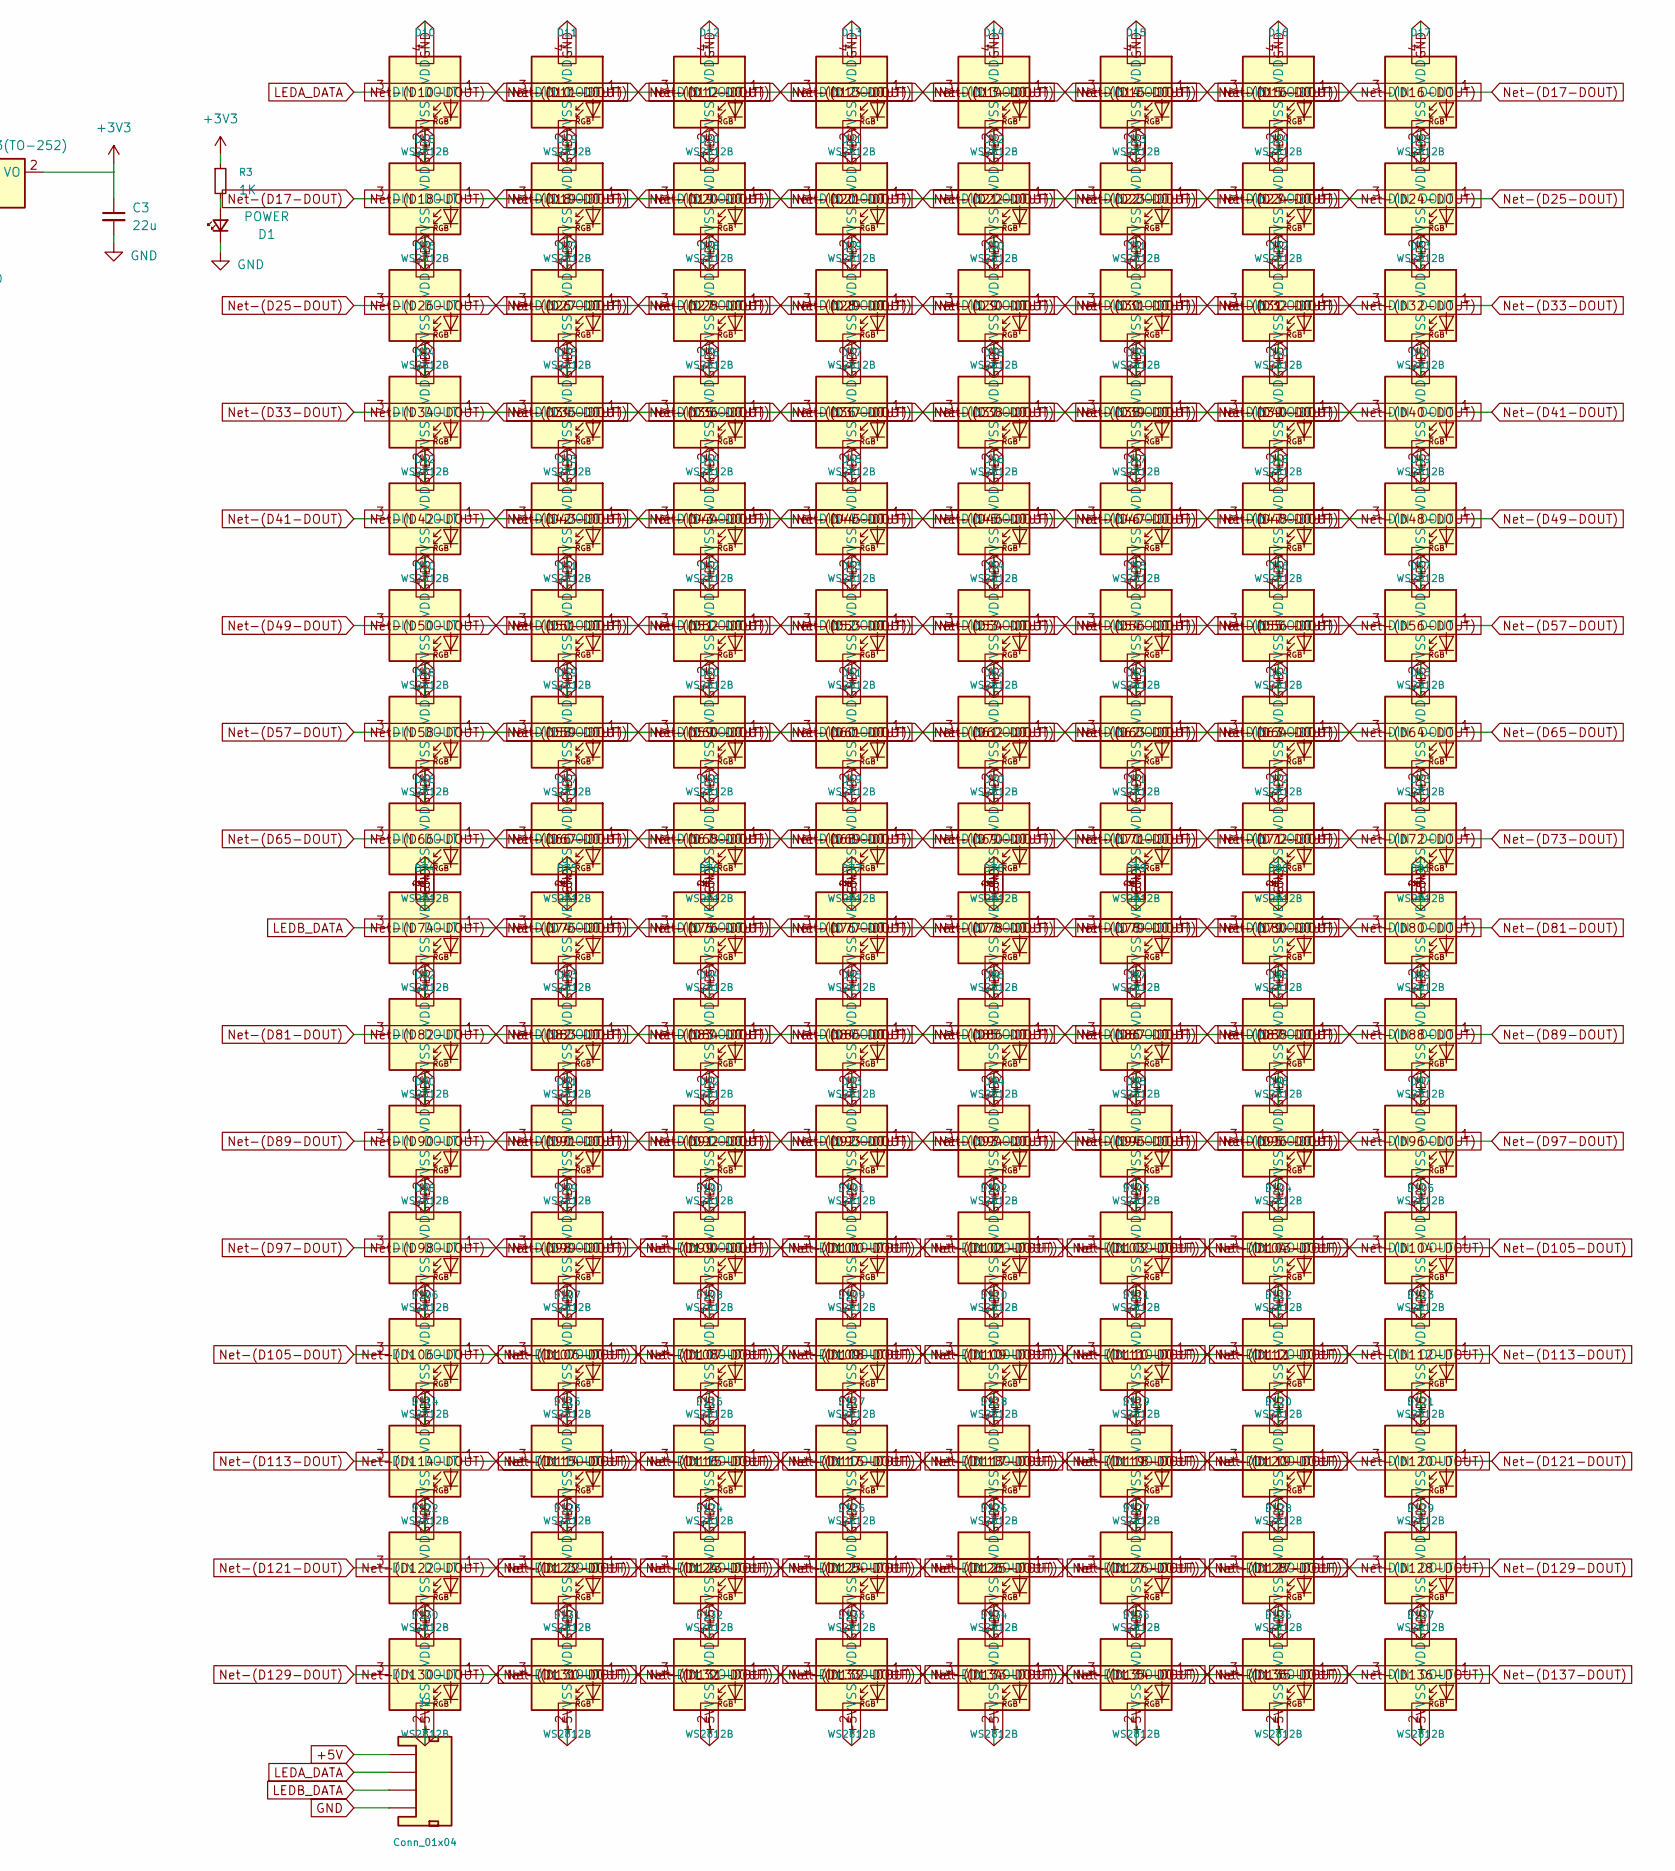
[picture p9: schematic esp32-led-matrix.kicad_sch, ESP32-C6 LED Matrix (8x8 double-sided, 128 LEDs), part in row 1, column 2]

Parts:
C1, C6: 100n; C_01005_0402Metric; MPN CL02A104MQ2NNNC; LCSC C307376
C2, C3: 22u; C_0805_2012Metric; MPN 0805X226M160NT; LCSC C129302
C4: 1u; C_0603_1608Metric; MPN CL10A105KB8NNNC; LCSC C15849
C5: 10u; C_0603_1608Metric; MPN HGC0603R5106M160NTHJ; LCSC C7472959
D1: POWER; LED_0603_1608Metric; MPN KT-0603R; LCSC C2286
D4: ESD9B3.3ST5G; D_SOD-923; MPN ESD9B3.3ST5G; LCSC C96512
D10, D11, D12, D13, D14, D15, D16, D17, D18, D19, D20, D21, D22, D23, D24, D25, D26, D27, D28, D29, D30, D31, D32, D33, D34, D35, D36, D37, D38, D39, D40, D41, D42, D43, D44, D45, D46, D47, D48, D49, D50, D51, D52, D53, D54, D55, D56, D57, D58, D59, D60, D61, D62, D63, D64, D65, D66, D67, D68, D69, D70, D71, D72, D73, D74, D75, D76, D77, D78, D79, D80, D81, D82, D83, D84, D85, D86, D87, D88, D89, D90, D91, D92, D93, D94, D95, D96, D97, D98, D99, D100, D101, D102, D103, D104, D105, D106, D107, D108, D109, D110, D111, D112, D113, D114, D115, D116, D117, D118, D119, D120, D121, D122, D123, D124, D125, D126, D127, D128, D129, D130, D131, D132, D133, D134, D135, D136, D137: WS2812B; WS2812_2020; MPN XL-2020RGBC-2812B; LCSC C5349955
J2: Conn_01x04; JST_1x04_P2.0mm_Horizontal_SMD; MPN WAFER-PH2.0-4PWB; LCSC C3029442
J4: USB_C_Receptacle_USB2.0_16P; USB_C_Receptacle_GCT_USB4105-xx-A_16P_TopMnt_Horizontal; MPN USB4105-GF-A; LCSC C3020560
R1, R2: 5.1K; R_0402_1005Metric_Pad0.72x0.64mm_HandSolder; MPN 0402WGF5101TCE; LCSC C25905
R3: 1K; R_0402_1005Metric_Pad0.72x0.64mm_HandSolder; MPN 0402WGF1001TCE; LCSC C11702
R7, R8: 10K; R_0402_1005Metric_Pad0.72x0.64mm_HandSolder; MPN 0402WGF1002TCE; LCSC C25744
SW1: RESET; SW_SPST_B3U-1000P; MPN B3U-1000P; LCSC C231329
U1: ESP32-C6-WROOM-1-N8; ESP32-C6-WROOM-1; MPN ESP32-C6-WROOM-1-N8; LCSC C5366877
U2: USBLC6-2SC6; SOT-23-6; MPN USBLC6-2SC6-FS; LCSC C6807798
U3: AMS1117-3.3(TO-252); TO-252-3_TabPin2; MPN AMS1117-3.3(TO-252); LCSC C41347676

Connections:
+3V3: C3.1, C5.1, C6.1, R3.1, R7.1, R8.1, U1.2 (3V3), U3.2 (VO)
CC1: J4.A5 (CC1), R1.1
CC2: J4.B5 (CC2), R2.1
GPIO3: R8.2, U1.26 (GPIO3/ADC1_CH3)
LEDA_DATA: D10.3 (DIN), J2.2, U1.6 (MTCK/GPIO6/ADC1_CH6)
LEDB_DATA: D74.3 (DIN), J2.3, U1.7 (MTDO/GPIO7)
unnamed: D1.2 (A), R3.2
unnamed: D10.1 (DOUT), D11.3 (DIN)
unnamed: D11.1 (DOUT), D12.3 (DIN)
unnamed: D12.1 (DOUT), D13.3 (DIN)
unnamed: D13.1 (DOUT), D14.3 (DIN)
unnamed: D14.1 (DOUT), D15.3 (DIN)
unnamed: D15.1 (DOUT), D16.3 (DIN)
unnamed: D16.1 (DOUT), D17.3 (DIN)
unnamed: D17.1 (DOUT), D18.3 (DIN)
unnamed: D18.1 (DOUT), D19.3 (DIN)
unnamed: D19.1 (DOUT), D20.3 (DIN)
unnamed: D20.1 (DOUT), D21.3 (DIN)
unnamed: D21.1 (DOUT), D22.3 (DIN)
unnamed: D22.1 (DOUT), D23.3 (DIN)
unnamed: D23.1 (DOUT), D24.3 (DIN)
unnamed: D24.1 (DOUT), D25.3 (DIN)
unnamed: D25.1 (DOUT), D26.3 (DIN)
unnamed: D26.1 (DOUT), D27.3 (DIN)
unnamed: D27.1 (DOUT), D28.3 (DIN)
unnamed: D28.1 (DOUT), D29.3 (DIN)
unnamed: D29.1 (DOUT), D30.3 (DIN)
unnamed: D30.1 (DOUT), D31.3 (DIN)
unnamed: D31.1 (DOUT), D32.3 (DIN)
unnamed: D32.1 (DOUT), D33.3 (DIN)
unnamed: D33.1 (DOUT), D34.3 (DIN)
unnamed: D34.1 (DOUT), D35.3 (DIN)
unnamed: D35.1 (DOUT), D36.3 (DIN)
unnamed: D36.1 (DOUT), D37.3 (DIN)
unnamed: D37.1 (DOUT), D38.3 (DIN)
unnamed: D38.1 (DOUT), D39.3 (DIN)
unnamed: D39.1 (DOUT), D40.3 (DIN)
unnamed: D40.1 (DOUT), D41.3 (DIN)
unnamed: D41.1 (DOUT), D42.3 (DIN)
unnamed: D42.1 (DOUT), D43.3 (DIN)
unnamed: D43.1 (DOUT), D44.3 (DIN)
unnamed: D44.1 (DOUT), D45.3 (DIN)
unnamed: D45.1 (DOUT), D46.3 (DIN)
unnamed: D46.1 (DOUT), D47.3 (DIN)
unnamed: D47.1 (DOUT), D48.3 (DIN)
unnamed: D48.1 (DOUT), D49.3 (DIN)
unnamed: D49.1 (DOUT), D50.3 (DIN)
unnamed: D50.1 (DOUT), D51.3 (DIN)
unnamed: D51.1 (DOUT), D52.3 (DIN)
unnamed: D52.1 (DOUT), D53.3 (DIN)
unnamed: D53.1 (DOUT), D54.3 (DIN)
unnamed: D54.1 (DOUT), D55.3 (DIN)
unnamed: D55.1 (DOUT), D56.3 (DIN)
unnamed: D56.1 (DOUT), D57.3 (DIN)
unnamed: D57.1 (DOUT), D58.3 (DIN)
unnamed: D58.1 (DOUT), D59.3 (DIN)
unnamed: D59.1 (DOUT), D60.3 (DIN)
unnamed: D60.1 (DOUT), D61.3 (DIN)
unnamed: D61.1 (DOUT), D62.3 (DIN)
unnamed: D62.1 (DOUT), D63.3 (DIN)
unnamed: D63.1 (DOUT), D64.3 (DIN)
unnamed: D64.1 (DOUT), D65.3 (DIN)
unnamed: D65.1 (DOUT), D66.3 (DIN)
unnamed: D66.1 (DOUT), D67.3 (DIN)
unnamed: D67.1 (DOUT), D68.3 (DIN)
unnamed: D68.1 (DOUT), D69.3 (DIN)
unnamed: D69.1 (DOUT), D70.3 (DIN)
unnamed: D70.1 (DOUT), D71.3 (DIN)
unnamed: D71.1 (DOUT), D72.3 (DIN)
unnamed: D72.1 (DOUT), D73.3 (DIN)
unnamed: D74.1 (DOUT), D75.3 (DIN)
unnamed: D75.1 (DOUT), D76.3 (DIN)
unnamed: D76.1 (DOUT), D77.3 (DIN)
unnamed: D77.1 (DOUT), D78.3 (DIN)
unnamed: D78.1 (DOUT), D79.3 (DIN)
unnamed: D79.1 (DOUT), D80.3 (DIN)
unnamed: D80.1 (DOUT), D81.3 (DIN)
unnamed: D81.1 (DOUT), D82.3 (DIN)
unnamed: D82.1 (DOUT), D83.3 (DIN)
unnamed: D83.1 (DOUT), D84.3 (DIN)
unnamed: D84.1 (DOUT), D85.3 (DIN)
unnamed: D85.1 (DOUT), D86.3 (DIN)
unnamed: D86.1 (DOUT), D87.3 (DIN)
unnamed: D87.1 (DOUT), D88.3 (DIN)
unnamed: D88.1 (DOUT), D89.3 (DIN)
unnamed: D89.1 (DOUT), D90.3 (DIN)
unnamed: D90.1 (DOUT), D91.3 (DIN)
unnamed: D91.1 (DOUT), D92.3 (DIN)
unnamed: D92.1 (DOUT), D93.3 (DIN)
unnamed: D93.1 (DOUT), D94.3 (DIN)
unnamed: D94.1 (DOUT), D95.3 (DIN)
unnamed: D95.1 (DOUT), D96.3 (DIN)
unnamed: D96.1 (DOUT), D97.3 (DIN)
unnamed: D97.1 (DOUT), D98.3 (DIN)
unnamed: D98.1 (DOUT), D99.3 (DIN)
unnamed: D99.1 (DOUT), D100.3 (DIN)
unnamed: D100.1 (DOUT), D101.3 (DIN)
unnamed: D101.1 (DOUT), D102.3 (DIN)
unnamed: D102.1 (DOUT), D103.3 (DIN)
unnamed: D103.1 (DOUT), D104.3 (DIN)
unnamed: D104.1 (DOUT), D105.3 (DIN)
unnamed: D105.1 (DOUT), D106.3 (DIN)
unnamed: D106.1 (DOUT), D107.3 (DIN)
unnamed: D107.1 (DOUT), D108.3 (DIN)
unnamed: D108.1 (DOUT), D109.3 (DIN)
unnamed: D109.1 (DOUT), D110.3 (DIN)
unnamed: D110.1 (DOUT), D111.3 (DIN)
unnamed: D111.1 (DOUT), D112.3 (DIN)
unnamed: D112.1 (DOUT), D113.3 (DIN)
unnamed: D113.1 (DOUT), D114.3 (DIN)
unnamed: D114.1 (DOUT), D115.3 (DIN)
unnamed: D115.1 (DOUT), D116.3 (DIN)
unnamed: D116.1 (DOUT), D117.3 (DIN)
unnamed: D117.1 (DOUT), D118.3 (DIN)
unnamed: D118.1 (DOUT), D119.3 (DIN)
unnamed: D119.1 (DOUT), D120.3 (DIN)
unnamed: D120.1 (DOUT), D121.3 (DIN)
unnamed: D121.1 (DOUT), D122.3 (DIN)
unnamed: D122.1 (DOUT), D123.3 (DIN)
unnamed: D123.1 (DOUT), D124.3 (DIN)
unnamed: D124.1 (DOUT), D125.3 (DIN)
unnamed: D125.1 (DOUT), D126.3 (DIN)
unnamed: D126.1 (DOUT), D127.3 (DIN)
unnamed: D127.1 (DOUT), D128.3 (DIN)
unnamed: D128.1 (DOUT), D129.3 (DIN)
unnamed: D129.1 (DOUT), D130.3 (DIN)
unnamed: D130.1 (DOUT), D131.3 (DIN)
unnamed: D131.1 (DOUT), D132.3 (DIN)
unnamed: D132.1 (DOUT), D133.3 (DIN)
unnamed: D133.1 (DOUT), D134.3 (DIN)
unnamed: D134.1 (DOUT), D135.3 (DIN)
unnamed: D135.1 (DOUT), D136.3 (DIN)
unnamed: D136.1 (DOUT), D137.3 (DIN)
USB_D+: U1.14 (GPIO13/USB_D+), U2.6 (I/O1)
USB_D-: U1.13 (GPIO12/USB_D-), U2.4 (I/O2)

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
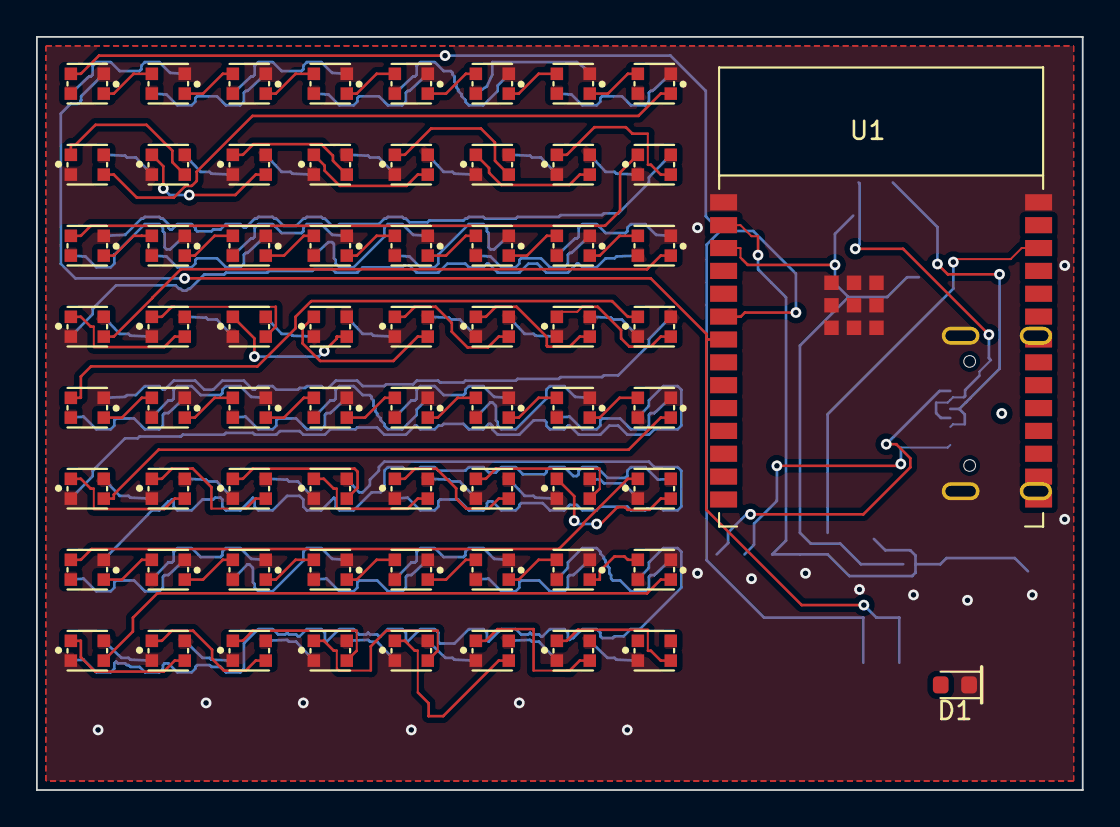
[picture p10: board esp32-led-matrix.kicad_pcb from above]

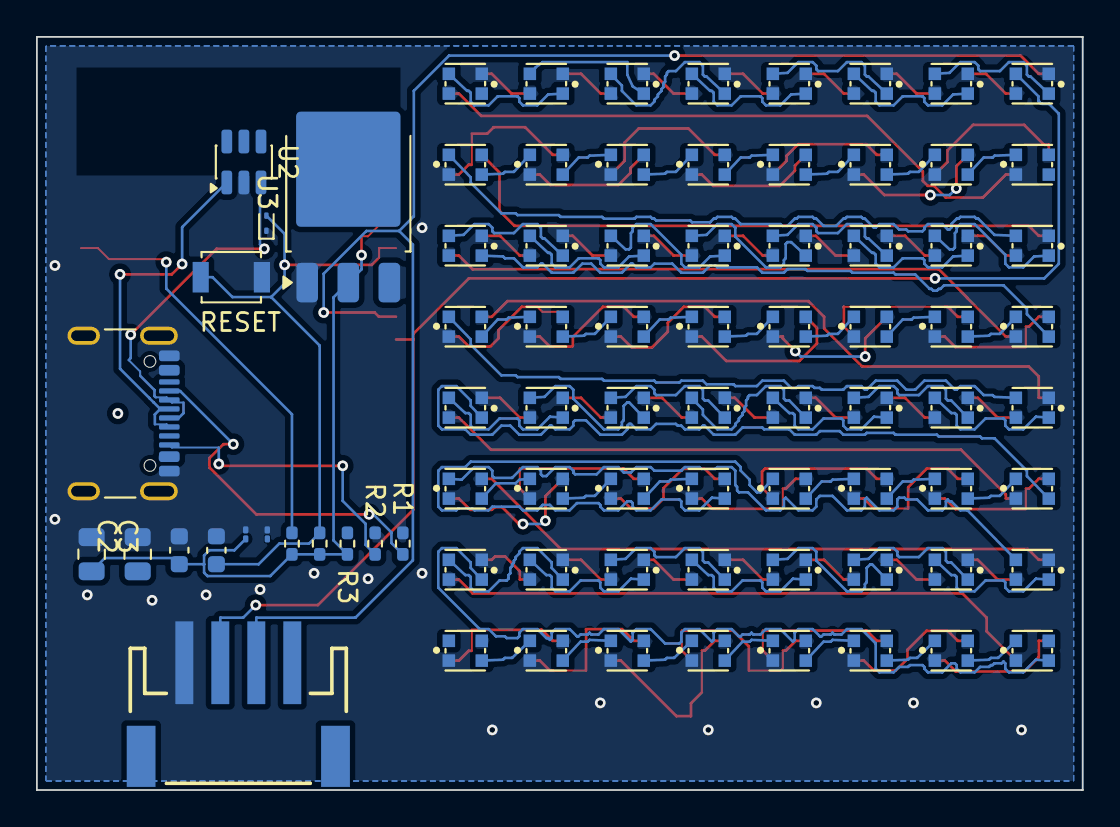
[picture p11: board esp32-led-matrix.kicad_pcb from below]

Board: 2 copper layers, 58.1 x 41.8 mm, 147 parts (81 on the bottom side), 140 nets.

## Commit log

2026-09-25 first run
    [esp32-led-matrix.kicad_pcb, esp32-led-matrix.kicad_sch]
2026-09-25 Fix broken PCB routing via Freerouting autorouter; add BOM/fab-files/docs/README
    - Cleared all hand-routed copper (577 traces, all shorted/crossing) and
    re-routed via the Freerouting autorouter (v2.1.0, Java-21 compatible
    build — v2.4.1 shipped requires Java 25 which isn't installed)
    - Fixed GND/+5V zone priority bug: both power-pour zones defaulted to
    overlapping full-board fills with +5V outranking GND, starving GND
    fill to near-zero; swapped priorities and added connect_pads=yes for
    solid (non-thermal-relief) GND pad connections
    - Added ~700 GND stitching vias (F.Cu<->B.Cu pour bridging) across
    several tuned passes, removing colliding/clearance-violating ones
    - Re-ran Freero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
    [BOM_jlcpcb_verified.csv, bom.csv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]
2026-09-26 Add JLCPCB-verified component library (lib_jlcpcb/) with real 3D models; attach verified STEP model to J2 connector; document library verification in README
    - Verified live JLCPCB stock for LED (XL-2020RGBC-2812B, C5349955: 128,513
    units) and JST-PH connector (WAFER-PH2.0-4PWB, C3029442: 45,706 units) via
    the JLCPCB Open Platform API.
    - Generated a complete symbol+footprint+3D-model bundle for both parts
    directly from LCSC's EasyEDA source data (easyeda2kicad), saved to
    lib_jlcpcb/ — each symbol carries its live datasheet URL and LCSC part
    number.
    - Fixed the previously-documented missing-3D-model gap on J2 (JST connector)
    by attaching the new verified STEP model to the existin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
    [esp32-led-matrix.kicad_pcb]
2026-09-26 Checkpoint before full layout redesign: add layout sketch proposals for reference
    Design approved by user: 8x8 LED matrix on each side unchanged, ESP32-C6 alone
    on top layer (F.Cu) beside LED matrix A, USB-C/JST/regulator/ESD/switch/passives
    on bottom layer (B.Cu) beside LED matrix B. USB-C centered on right edge, JST at
    bottom edge, regulator+ESD clustered near USB-C. Board target: ~57.25 x 36.7mm.
2026-09-26 Add exact coordinate spec for new board layout
2026-09-26 Move board outline and both LED matrices to new compact layout positions (routing intentionally broken, fixed in later task)
    [esp32-led-matrix.kicad_pcb]
2026-09-26 Reposition ESP32-C6 module and verify antenna keepout zone follows it correctly
    [esp32-led-matrix.kicad_pcb]
2026-09-26 Reposition USB-C (right edge), JST (bottom edge), and remaining B.Cu components per approved layout
    [esp32-led-matrix.kicad_pcb]
2026-09-26 Clear all stale copper (traces/vias/zones) from old layout, ready for fresh routing
    [esp32-led-matrix.kicad_pcb]
2026-09-26 Re-route board via Freerouting on new compact layout, add GND/+5V zones
    - Added fresh GND/+5V copper pour zones (F.Cu + B.Cu) sized to the new
    57.25 x 41.84mm board outline (0.5mm inset), replicating zone
    settings from commit b6e9c1f (priority, connect_pads=yes,
    clearance=0.3mm, thermal relief 0.3mm) via pcbnew Python API.
    GND kept at priority 1 (wins over +5V priority 0) per the
    priority-bug fix documented in commit 5a5434d.
    - Routed all copper via Freerouting. The pre-installed Java-21
    v2.1.0 jar (from a prior session's workaround) reliably found a
    route candidate within seconds but then hung indefinitely in CLI
    mode without ever writing the SES file (matches upstream issue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
    [esp32-led-matrix.kicad_pcb]
2026-09-26 Finalize redesigned compact layout: DRC/ERC cleanup, regenerate fab files and docs, update README
    - Fixed stale zone fill from task 6 (Freerouting SES import left GND/+5V
    pours unfilled, causing 382 phantom DRC violations); single ZONE_FILLER
    refill dropped this to 128 baseline violations (100 lib_footprint_mismatch
    + 28 genuine pre-existing issues, documented in README).
    - Fixed D1 (power LED) placement bug: was left at y=53mm, outside the
    41.84mm board height (leftover coordinate error from before this redesign
    series). Relocated to a clear F.Cu spot at (51, 36).
    - Hand-routed Net-(D79-DOUT) LED daisy-chain gap (0 new violations,
    clearance-verified per segment before committing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
    [esp32-led-matrix-B_Cu.gbl, esp32-led-matrix-B_Mask.gbs, esp32-led-matrix-B_Silkscreen.gbo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]
